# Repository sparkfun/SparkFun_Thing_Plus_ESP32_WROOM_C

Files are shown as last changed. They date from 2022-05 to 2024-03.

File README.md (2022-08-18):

SparkFun Thing Plus - ESP32 WROOM (USB-C)
========================================

SparkFun Thing Plus - ESP32 WROOM (USB-C) (https://www.sparkfun.com/products/20168)

*[SparkFun Thing Plus - ESP32 WROOM (USB-C) (WRL-20168)](https://www.sparkfun.com/products/20168)*

The [SparkFun Thing Plus - ESP32 WROOM (USB-C)](https://www.sparkfun.com/products/20168) is a comprehensive development platform for [Espressif's ESP32](https://espressif.com/en/products/hardware/esp32/overview). Thanks to the onboard ESP32 WROOM module, the SparkFun Thing Plus features 16MB of flash memory, 520kB of internal SRAM, an integrated 802.11 BGN WiFi transceiver and dual-mode Bluetooth capabilities, a JST connector to plug in a LiPo battery, a Qwiic connector, and 21 I/O pins. Add to that a rich set of peripherals ranging from capacitive touch sensors, Hall sensors, SD card interface, Ethernet, high-speed SPIs, UARTs, I2S, and I<sup>2</sup>C.

We took all the good from the original [ESP32 Thing Plus](https://www.sparkfun.com/products/15663) and sprinkled on some more. We upgraded to a USB-C connector that provides up to 2A of power, added a fuel gauge IC that will make sure you know your battery levels, included a NeoPixel (WS2812C) RGB LED is the perfect multi-status indicator, and threw a microSD connector on the back! Oh, and the new taller reset and boot buttons are **so** much easier to push! We even dedicated a voltage regulator to the Qwiic connector, which enables software power control to the Qwiic bus - great for low power logging!

Repository Contents
-------------------

* **[/Hardware](/Hardware/)** - Eagle design files (.brd, .sch)
* **[/Firmware](/Firmware/)** - Example sketches demonstrating extra peripherals

Documentation
--------------
* **[Hookup Guide](https://learn.sparkfun.com/tutorials/2353)** - Hookup guide for the ESP32 Thing Plus (USB-C).
* **[SparkFun Graphical Datasheets](https://github.com/sparkfun/Graphical_Datasheets)** -Graphical Datasheets for various SparkFun products.

Product Versions
----------------
* ESP32 Thing Plus (USB-C variant)
  * [WRL-20168](https://www.sparkfun.com/products/20168) - v1.0, Initial Release
  * [SPX-18018](https://www.sparkfun.com/products/18018) - SparkX Release
* ESP32 Thing Plus
  * [WRL-17381](https://www.sparkfun.com/products/17381) (u.FL variant) - v1.0, Initial Release
  * [WRL-15663](https://www.sparkfun.com/products/15663)- v2.0, Slight hardware update that includes a 10&ohm; series resistor between VUSB and CP2102
  * [WRL-14689](https://www.sparkfun.com/products/14689)- v1.0, Initial Release

License Information
-------------------

This product is _**open source**_! 

Please review the LICENSE.md file for license information. 

If you have any questions or concerns on licensing, please contact technical support on our [SparkFun forums](https://forum.sparkfun.com/viewforum.php?f=152).

Distributed as-is; no warranty is given.

- Your friends at SparkFun.

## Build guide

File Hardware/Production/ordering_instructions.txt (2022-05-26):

panel size, 107x204mm
PCB thickness, 1.6mm
number of layers, 2
soldermask color, Red
silkscreen color, White
oz copper, 1oz
finish, HASL lead free
stencils, none
pcs per panel, 12
min trace width, 0.1270mm / 0.0050in
min drill size, 0.3048mm / 0.0120in

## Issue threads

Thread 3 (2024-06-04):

High Leakage From VBAT to VBUS

DominicChm, 2024-06-04:
This issue is spawned from the Sparkfun forum post [here](https://forum.sparkfun.com/viewtopic.php?p=249708#p249708).

I've noticed the [Thing Plus USB-C](https://www.sparkfun.com/products/20168) has an issue with high leakage from VBATT to VBUS when only the battery is connected. From testing I've done on my own board, the issue appears to be that D4  has extremely poor reverse leakage (along the lines of the [Infineon BAT60A](https://www.infineon.com/dgdl/Infineon-BAT60ASERIES-DS-v01_01-en.pdf?fileId=db3a304313d846880113def70c9304a9)) which allows a non-negligible amount of current to flow through R7 when on battery.

<details>
  <summary>Schematic</summary>

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

</details>

On my board, this results in VBUS being pulled to 2.5V when on battery power when it really should be ~0V. Given the 10K pulldown on this rail, it seems about 250uA is reverse leaking through the diode. The ESP32's deep sleep current is specced at ~10uA, so this leakage represents an obstacle to battery-powered projects.

This issue also prevents effectively recognizing when power is coming from USB vs when it's coming from battery b/c the rail never drops low enough to be registered as a digital LOW by the ESP32 (.25v). In my application this prevents me from setting the ESP to wake from deep sleep when USB power is supplied. I've mitigated by adding a 500ohm resistor to pull the rail low harder but I really wish this wasn't a problem in the first place.

Whatever diode is in the BOM really ought to be replaced with one that has a better reverse leakage spec. It looks like there's probably enough space on the PCB to even include one with a larger package which should allow the existing spec to be met without the reverse leakage problem.

DominicChm, 2024-06-06:
Update: Bodged in a random large(r) diode from a scrap PCB I had lying around and the issue is resolved as suspected. I now measure `.0002v`  under the same conditions as above. Original diode is to the right of the bodged diode for reference.

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

brhoff720, 2024-06-07:
Thanks Dominic!  Glad you were able to get the performance you needed.

We appreciate the feedback on this.  We'll need to evaluate and likely get
a bom change made,.  It might be a bit before it makes it into production.

Thanks again!

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

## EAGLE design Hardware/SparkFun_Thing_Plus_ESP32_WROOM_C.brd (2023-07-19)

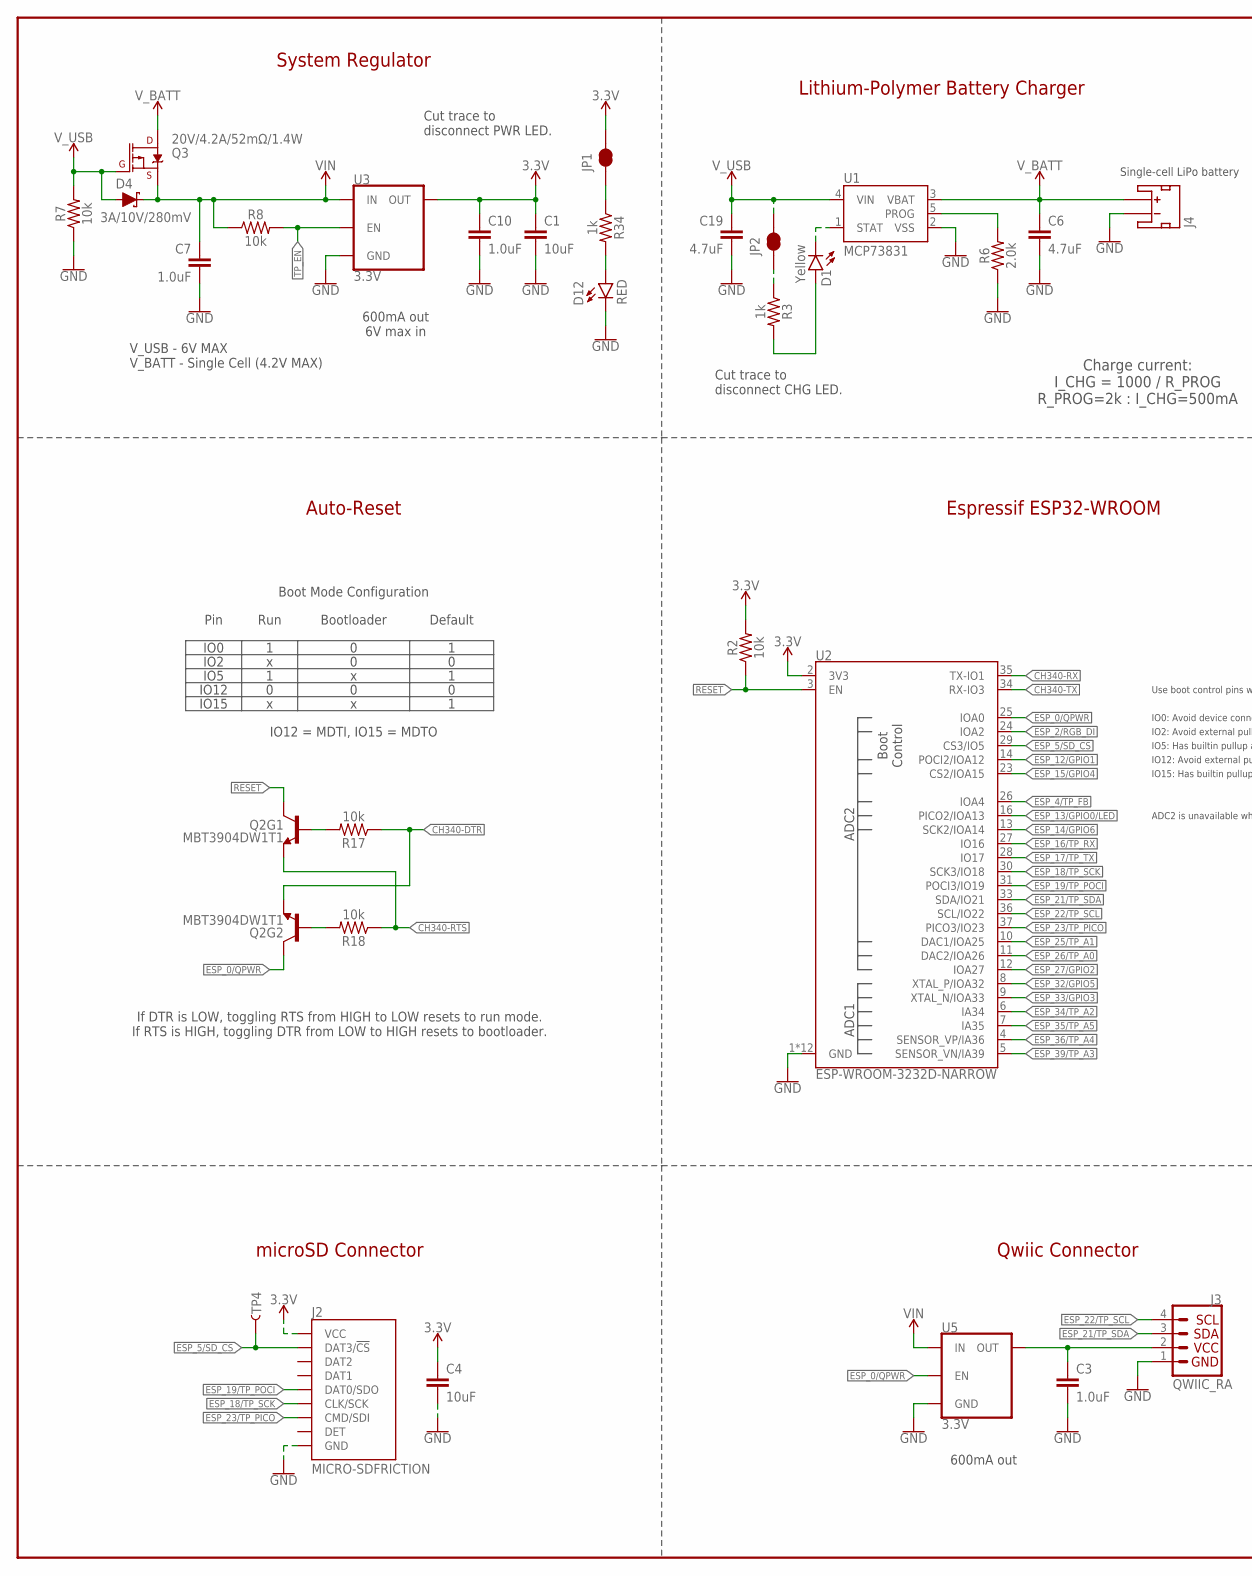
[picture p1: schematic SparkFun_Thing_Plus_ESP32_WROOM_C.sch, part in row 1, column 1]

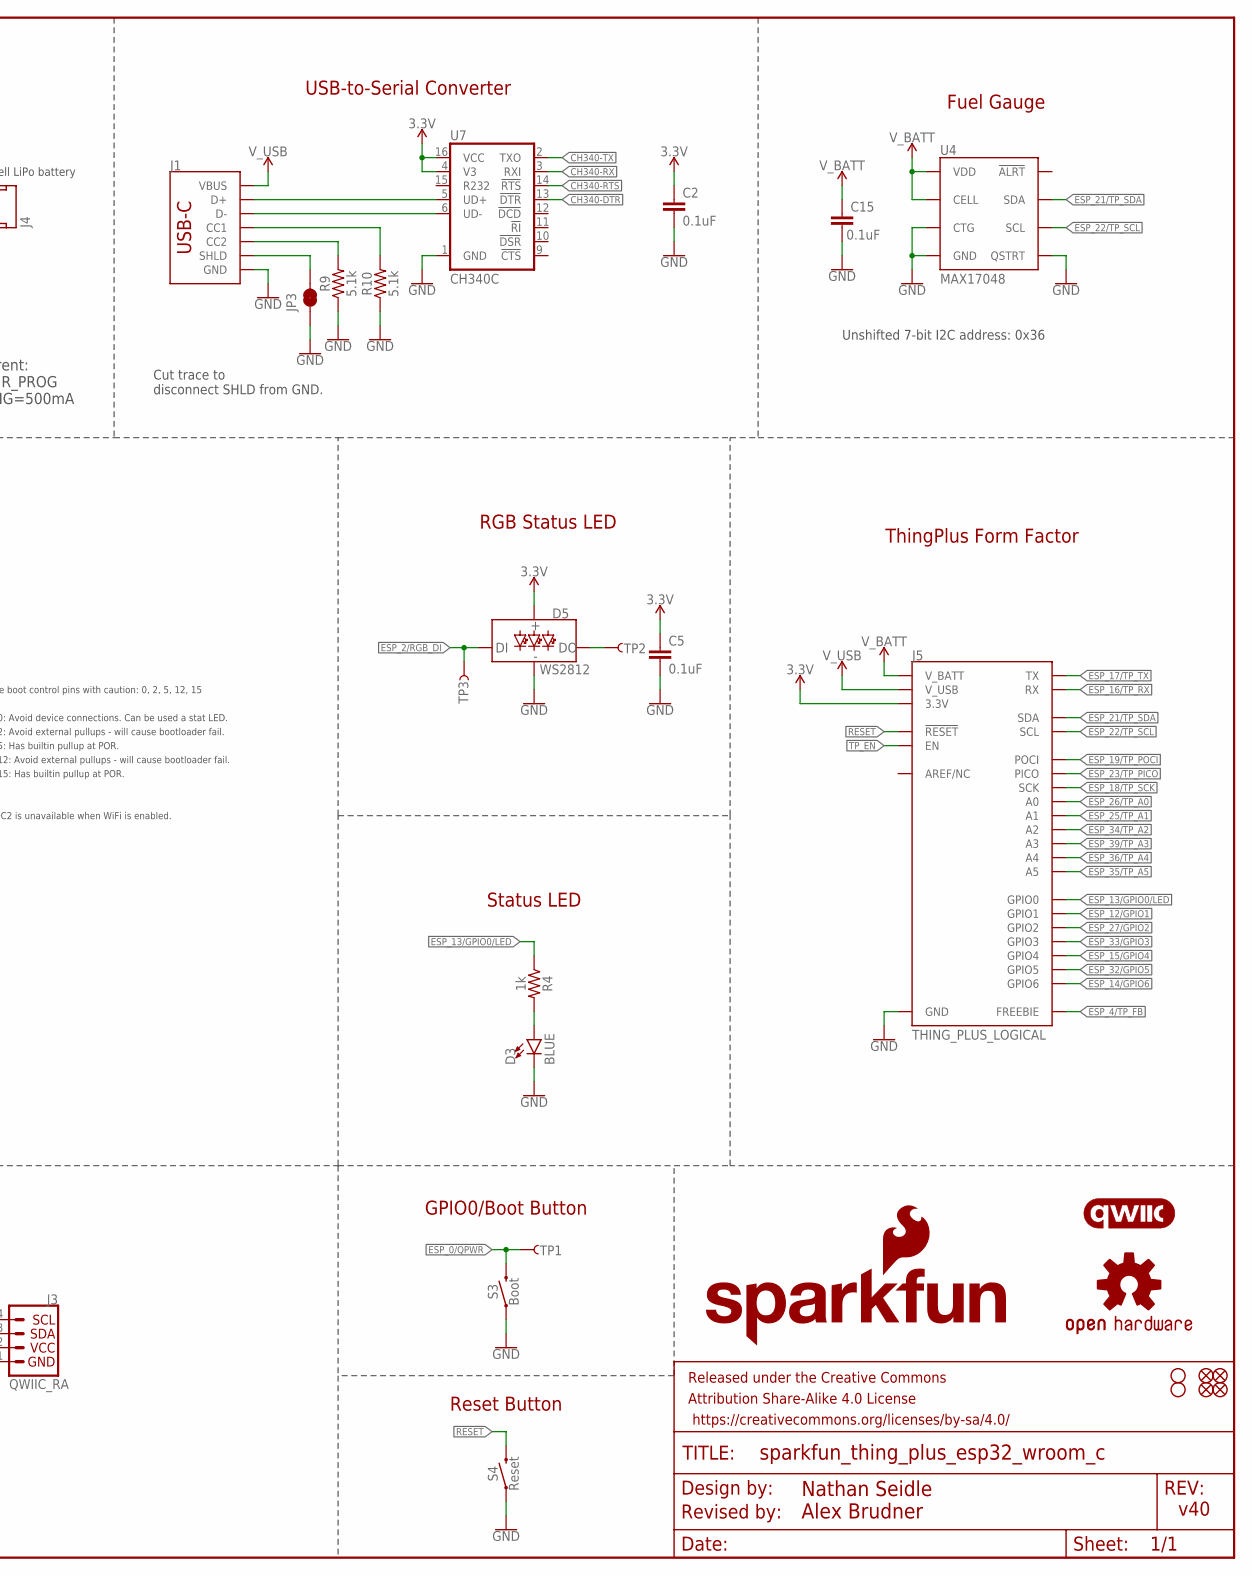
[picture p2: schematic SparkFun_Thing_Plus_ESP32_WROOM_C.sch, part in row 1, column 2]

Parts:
C1, C4: 10uF; 0402-TIGHT
C2, C5, C15: 0.1uF; 0402-TIGHT
C3, C7, C10: 1.0uF; 0402-TIGHT
C6: 4.7uF; 0402-TIGHT
C19: 4.7uF; 0603
D1: Yellow; LED-0603
D3: BLUE; LED-0603
D4: 3A/10V/280mV; SOD-323
D5: WS2812; WS2812-2020
D12: RED; LED-0603
FD1, FD2, FD3, FD4: FIDUCIALUFIDUCIAL; FIDUCIAL-MICRO
FRAME1: FRAME-LEDGER; CREATIVE_COMMONS
H1, H2: STAND-OFFTIGHT; STAND-OFF-TIGHT
J1: USB_C_2-LAYER_PADS; USB-C-16P-2LAYER-PADS
J2: MICRO-SDFRICTION; MICROSD_TINY
J3: QWIIC_RA; JST04_1MM_RA
J4: JST_2MM_MALE; JST-2-SMD
J5: THING_PLUS_LOGICAL; THING_PLUS
JP1, JP2, JP3: JUMPER-SMT_2_NC_TRACE_SILK; SMT-JUMPER_2_NC_TRACE_SILK
LOGO1: SFE_LOGO_NAME_FLAME.1_INCH; SFE_LOGO_NAME_FLAME_.1
LOGO2: OSHW-LOGOMINI; OSHW-LOGO-MINI
LOGO4: QWIIC_LOGO_4MM; QWIIC_4MM
Q2: MBT3904DW1T1; SC70-6
Q3: 20V/4.2A/52mΩ/1.4W; SOT23-3
R2, R7, R8, R17, R18: 10k; 0402-TIGHT
R3, R4, R34: 1k; 0402-TIGHT
R6: 2.0k; 0603
R9, R10: 5.1k; 0402-TIGHT
S3: Boot; TACTILE_SWITCH_SMD_4.6X2.8MM
S4: Reset; TACTILE_SWITCH_SMD_4.6X2.8MM
TP1, TP2, TP3, TP4: TEST-POINT3X5; PAD.03X.05
U1: MCP73831; SOT23-5
U2: ESP-WROOM-3232D-NARROW; ESP-WROOM-32D-NARROW
U3, U5: 3.3V; SOT23-5
U4: MAX17048; DFN-8
U7: CH340C; SO016

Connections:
3.3V: C1.1, C2.1, C4.1, C5.1, C10.1, D5.VCC, J2.4 (VCC), J5.27 (3.3V), JP1.2, R2.2, U2.2 (3V3), U3.5 (OUT), U7.4 (V3), U7.16 (VCC)
!RESET!: J5.28 (!RESET), Q2.3 (C), R2.1, S4.3 (2), S4.4 (2), U2.3 (EN)
CH340-DTR: Q2.1 (E), R17.1, U7.13 (!DTR)
CH340-RTS: Q2.4 (E), R18.1, U7.14 (!RTS)
CH340-RX: U2.35 (TX-IO1), U7.3 (RXI)
CH340-TX: U2.34 (RX-IO3), U7.2 (TXO)
CHG_LED: D1.A, R3.2
D+: J1.A6 (D+), J1.B6 (D+), U7.5 (UD+)
D-: J1.A7 (D-), J1.B7 (D-), U7.6 (UD-)
DTR-10K: Q2.5 (B), R17.2
ESP_0/QPWR: Q2.6 (C), S3.3 (2), S3.4 (2), TP1.1, U2.25 (IOA0), U5.3 (EN)
ESP_2/RGB_DI: D5.DI, TP3.1, U2.24 (IOA2)
ESP_4/TP_FB: J5.13 (FREEBIE), U2.26 (IOA4)
ESP_5/SD_CS: J2.2 (DAT3/!CS!), TP4.1, U2.29 (CS3/IO5)
ESP_12/GPIO1: J5.8 (GPIO1), U2.14 (POCI2/IOA12)
ESP_13/GPIO0/LED: J5.9 (GPIO0), R4.1, U2.16 (PICO2/IOA13)
ESP_14/GPIO6: J5.3 (GPIO6), U2.13 (SCK2/IOA14)
ESP_15/GPIO4: J5.5 (GPIO4), U2.23 (CS2/IOA15)
ESP_16/TP_RX: J5.15 (RX), U2.27 (IO16)
ESP_17/TP_TX: J5.14 (TX), U2.28 (IO17)
ESP_18/TP_SCK: J2.5 (CLK/SCK), J5.18 (SCK), U2.30 (SCK3/IO18)
ESP_19/TP_POCI: J2.7 (DAT0/SDO), J5.16 (POCI), U2.31 (POCI3/IO19)
ESP_21/TP_SDA: J3.3, J5.1 (SDA), U2.33 (SDA/IO21), U4.8 (SDA)
ESP_22/TP_SCL: J3.4, J5.2 (SCL), U2.36 (SCL/IO22), U4.7 (SCL)
ESP_23/TP_PICO: J2.3 (CMD/SDI), J5.17 (PICO), U2.37 (PICO3/IO23)
ESP_25/TP_A1: J5.23 (A1), U2.10 (DAC1/IOA25)
ESP_26/TP_A0: J5.24 (A0), U2.11 (DAC2/IOA26)
ESP_27/GPIO2: J5.7 (GPIO2), U2.12 (IOA27)
ESP_32/GPIO5: J5.4 (GPIO5), U2.8 (XTAL_P/IOA32)
ESP_33/GPIO3: J5.6 (GPIO3), U2.9 (XTAL_N/IOA33)
ESP_34/TP_A2: J5.22 (A2), U2.6 (IA34)
ESP_35/TP_A5: J5.19 (A5), U2.7 (IA35)
ESP_36/TP_A4: J5.20 (A4), U2.4 (SENSOR_VP/IA36)
ESP_39/TP_A3: J5.21 (A3), U2.5 (SENSOR_VN/IA39)
GND: C1.2, C2.2, C3.2, C4.2, C5.2, C6.2, C7.2, C10.2, C15.2, C19.2, D3.C, D5.GND, D12.C, J1.GND, J1.GND2 (GND), J2.6 (GND), J2.GND1 (GND), J2.GND2 (GND), J2.GND3 (GND), J2.GND4 (GND), J2.GND5 (GND), J2.GND6 (GND), J3.1, J4.1 (-), J5.25 (GND), JP3.1, R6.1, R7.1, R9.1, R10.1, S3.1, S3.2 (1), S4.1, S4.2 (1), U1.2 (VSS), U2.1 (GND), U2.15 (GND), U2.38 (GND), U2.GND1 (GND), U2.GNDT1 (GND), U2.GNDT2 (GND), U2.GNDT3 (GND), U2.GNDT4 (GND), U2.GNDT5 (GND), U2.GNDT6 (GND), U2.GNDT7 (GND), U2.GNDT8 (GND), U3.2 (GND), U4.1 (CTG), U4.4 (GND), U4.6 (QSTRT), U4.9 (GND), U5.2 (GND), U7.1 (GND)
unnamed: JP1.1, R34.1
unnamed: D3.A, R4.2
unnamed: D5.DO, TP2.1
unnamed: JP2.1, R3.1
unnamed: J1.B5 (CC2), R9.2
unnamed: J1.A5 (CC1), R10.2
unnamed: D1.C, U1.1 (STAT)
unnamed: J1.SHLD1 (SHLD), J1.SHLD2 (SHLD), J1.SHLD3 (SHLD), J1.SHLD4 (SHLD), JP3.2
unnamed: R6.2, U1.5 (PROG)
unnamed: D12.A, R34.2
QWIIC_PWR: C3.1, J3.2, U5.5 (OUT)
RTS-10K: Q2.2 (B), R18.2
TP_EN: J5.11 (EN), R8.2, U3.3 (EN)
VIN: C7.1, D4.C, Q3.2 (S), R8.1, U3.1 (IN), U5.1 (IN)
V_BATT: C6.1, C15.1, J4.2 (+), J5.12 (V_BATT), Q3.3 (D), U1.3 (VBAT), U4.2 (CELL), U4.3 (VDD)
V_USB: C19.1, D4.A, J1.VBUS1 (VBUS), J1.VBUS2 (VBUS), J5.10 (V_USB), JP2.2, Q3.1 (G), R7.2, U1.4 (VIN)

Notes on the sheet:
USB-to-Serial Converter
Single-cell LiPo battery
Charge current: I_CHG = 1000 / R_PROG R_PROG=2k : I_CHG=500mA
System Regulator
Lithium-Polymer Battery Charger
600mA out 6V max in
Auto-Reset
Espressif ESP32-WROOM
Reset Button
ThingPlus Form Factor
v40
If DTR is LOW, toggling RTS from HIGH to LOW resets to run mode. If RTS is HIGH, toggling DTR from LOW to HIGH resets to bootloader.
Qwiic Connector
Status LED
GPIO0/Boot Button
V_USB - 6V MAX V_BATT - Single Cell (4.2V MAX)
Pin
IO0
IO2
IO12
IO15
IO5
Run
Bootloader
Default
IO12 = MDTI, IO15 = MDTO
Boot Mode Configuration
IO0: Avoid device connections. Can be used a stat LED.
ADC2 is unavailable when WiFi is enabled.
IO12: Avoid external pullups - will cause bootloader fail.
Use boot control pins with caution: 0, 2, 5, 12, 15
IO2: Avoid external pullups - will cause bootloader fail.
Fuel Gauge
600mA out
RGB Status LED
microSD Connector
IO15: Has builtin pullup at POR.
IO5: Has builtin pullup at POR.
Cut trace to disconnect CHG LED.
Cut trace to disconnect PWR LED.

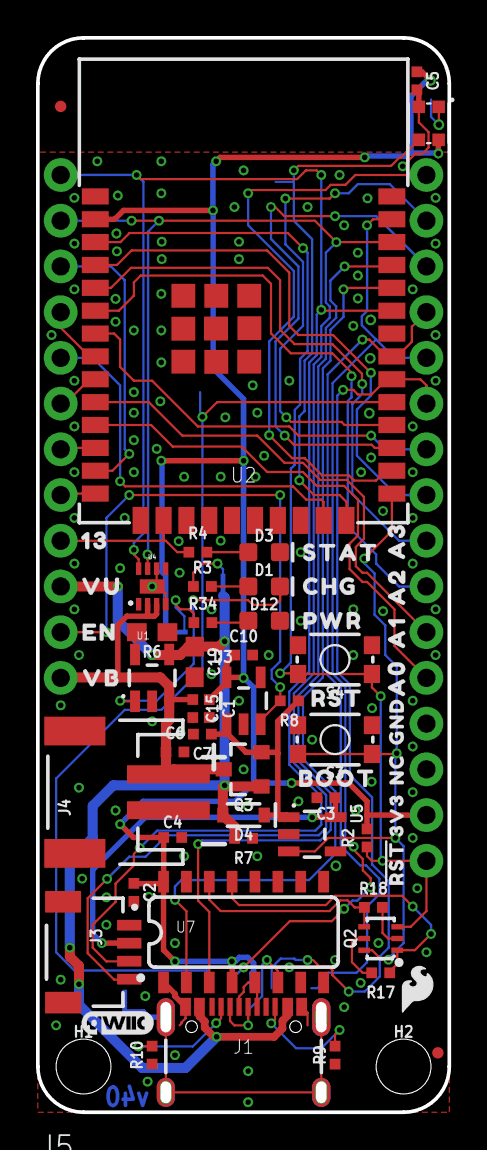
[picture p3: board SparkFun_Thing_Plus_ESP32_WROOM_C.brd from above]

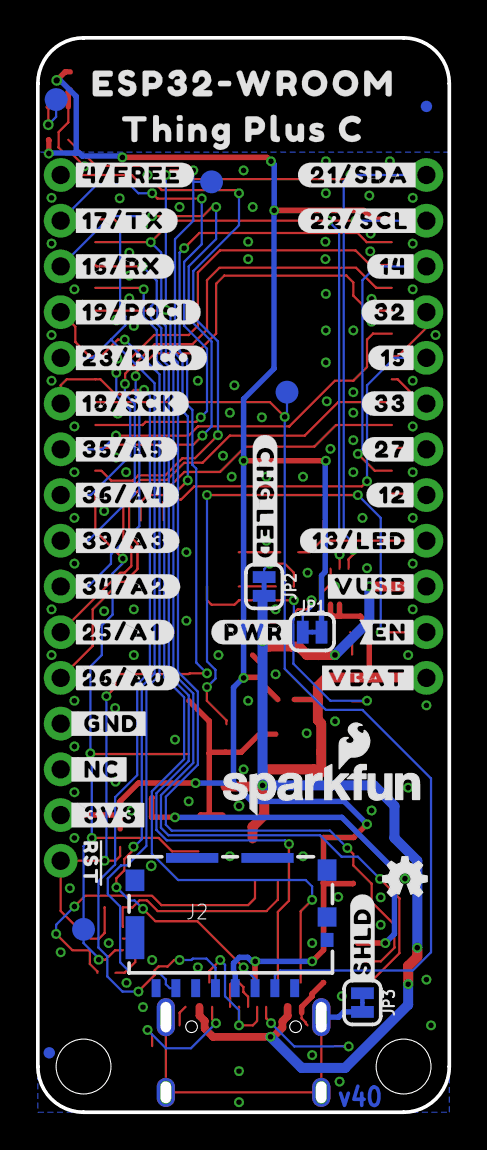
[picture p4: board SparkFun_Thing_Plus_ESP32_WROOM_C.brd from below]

Board: 2 copper layers, 22.9 x 59.7 mm, 110 parts (46 on the bottom side), 51 nets.

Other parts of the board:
U$1: SFE_LOGO_FLAME_STOP_.1
U$2: #23#PICO#0
U$3: #19#POCI#0
U$4: #4#FREE#0
U$5: #CHG_LED#0
U$6: ESP32#WROOM0
U$7: THING_PLUS_C0
U$8: #SHLD#0
U$9: #_GND#0
U$10: #_NC#0
U$11: #_3V3#0
U$12: SFE_LOGO_FLAME_.1
U$23: 3V30
U$24: CHG1
U$25: PWR2
U$26: STAT0
U$68: A03
U$69: A12
U$70: A21
U$71: A30
U$72: #17#TX#0
U$73: VB1
U$74: EN3
U$75: GND1
U$76: VU0
U$77: 130
U$78: BOOT0
U$79, U$109: #RST#0
U$80: RST0
U$81: #16#RX#0
U$83: #18#SCK#0
U$84: #35#A5#0
U$85: #36#A4#0
U$86: #25#A1#2
U$87: #26#A0#3
U$88: #34#A2#1
U$89: #39#A3#0
U$90: #12#4
U$91: #14#9
U$92: #15#7
U$93: #27#5
U$94: #32#8
U$95: #33#6
U$96: #EN#1
U$97: #VBAT#0
U$98: #VUSB#2
U$99: #13#LED#0
U$100: #21#SDA#1
U$101: #22#SCL#0
U$102: #PWR#0
U$107: NC0

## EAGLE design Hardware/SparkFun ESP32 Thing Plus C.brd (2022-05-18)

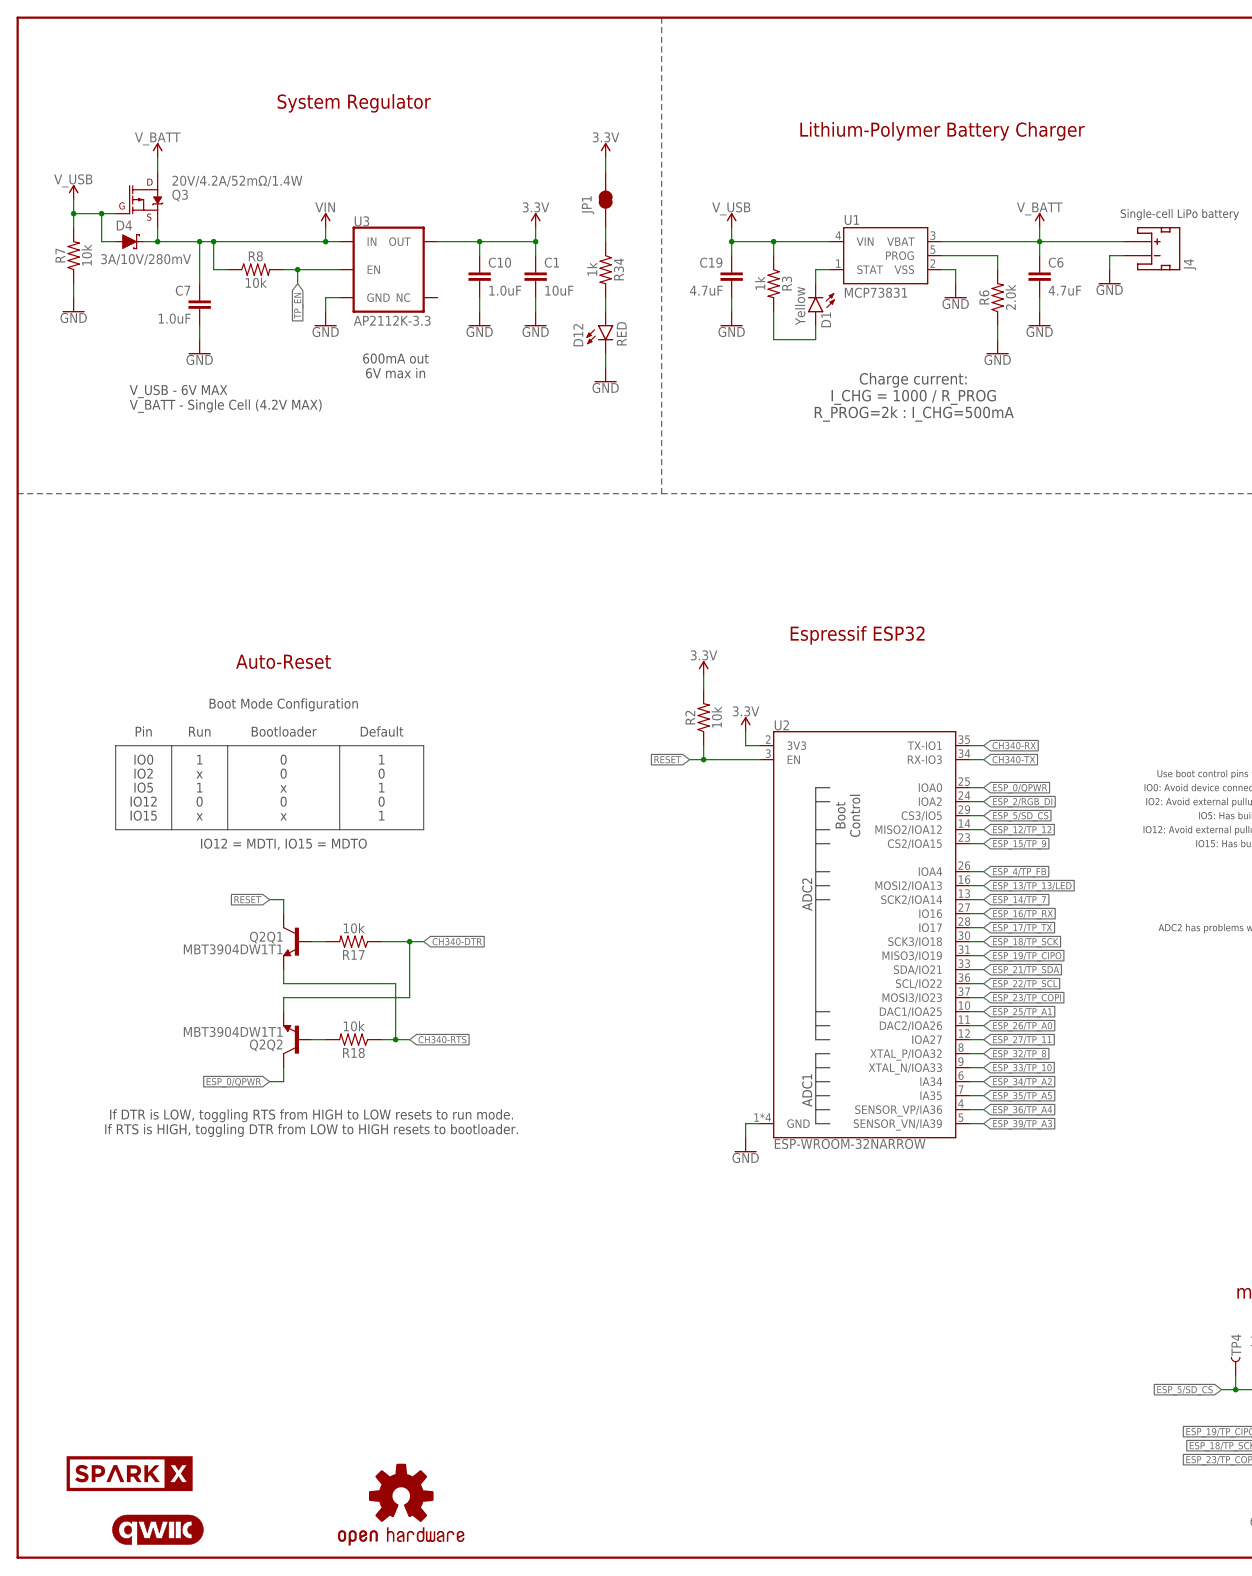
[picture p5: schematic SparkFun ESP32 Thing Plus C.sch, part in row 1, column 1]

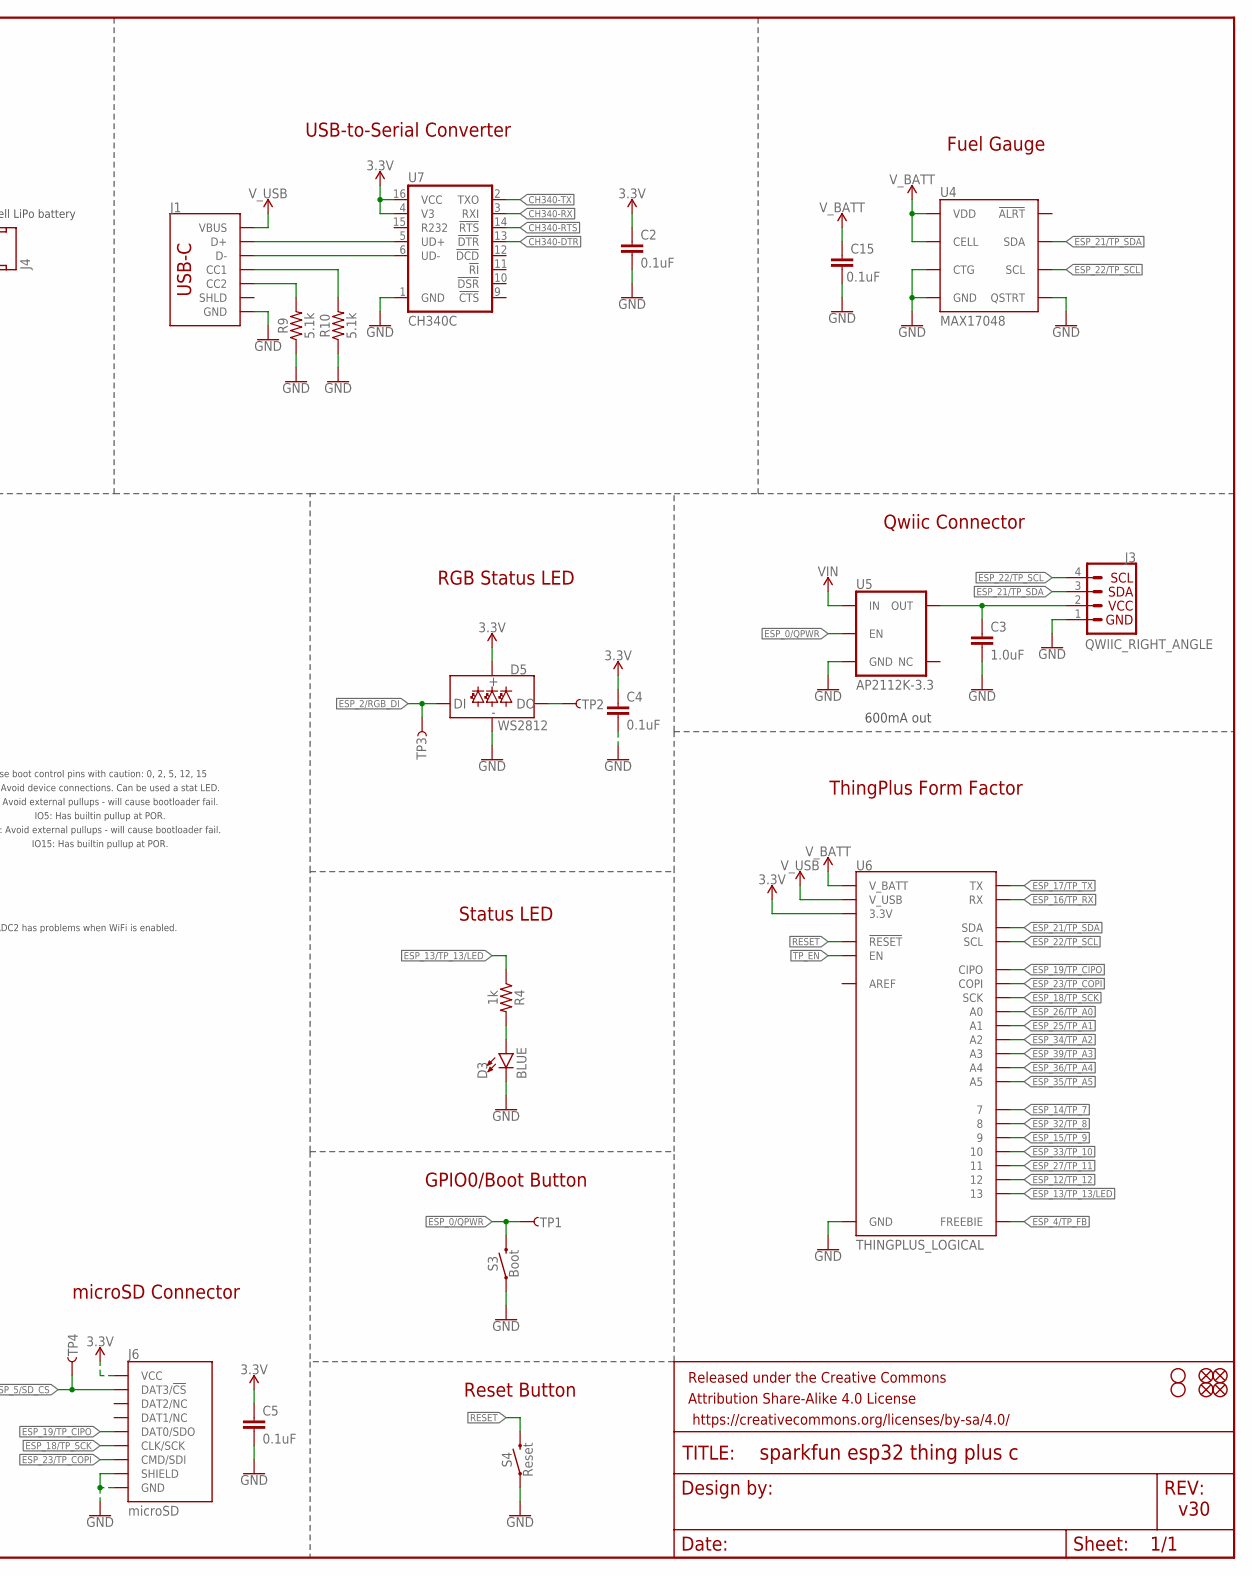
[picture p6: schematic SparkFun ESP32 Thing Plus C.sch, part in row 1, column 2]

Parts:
C1: 10uF; 0402-TIGHT
C2, C4, C5, C15: 0.1uF; 0402-TIGHT
C3, C7, C10: 1.0uF; 0402-TIGHT
C6: 4.7uF; 0402-TIGHT
C19: 4.7uF; 0603
D1: Yellow; LED-0603
D3: BLUE; LED-0603
D4: 3A/10V/280mV; SOD-323
D5: WS2812; WS2812-2020
D12: RED; LED-0603
FD1, FD2, FD3, FD4: FIDUCIALUFIDUCIAL; FIDUCIAL-MICRO
FRAME1: FRAME-LEDGER; CREATIVE_COMMONS
H1, H2: STAND-OFFTIGHT; STAND-OFF-TIGHT
J1: USB_C_2-LAYER_PADS; USB-C-16P-2LAYER-PADS
J3: QWIIC_RIGHT_ANGLE; JST04_1MM_RA
J4: JST_2MM_MALE; JST-2-SMD
J6: microSD; MICRO-SD-SOCKET
JP1: JUMPER-SMT_2_NC_TRACE_SILK; SMT-JUMPER_2_NC_TRACE_SILK
LOGO2: OSHW-LOGOMINI; OSHW-LOGO-MINI
LOGO4: QWIIC_LOGO_4MM; QWIIC_4MM
Q2: MBT3904DW1T1; SC70-6
Q3: 20V/4.2A/52mΩ/1.4W; SOT23-3
R2, R7, R8, R17, R18: 10k; 0402-TIGHT
R3, R4, R34: 1k; 0402-TIGHT
R6: 2.0k; 0603
R9, R10: 5.1k; 0402-TIGHT
S3: Boot; TACTILE_SWITCH_SMD_4.6X2.8MM
S4: Reset; TACTILE_SWITCH_SMD_4.6X2.8MM
TP1, TP2, TP3, TP4: TEST-POINT3X5; PAD.03X.05
U1: MCP73831; SOT23-5
U2: ESP-WROOM-32NARROW; ESP-WROOM-32-NARROW
U3, U5: AP2112K-3.3; SOT23-5
U4: MAX17048; DFN-8
U6: THINGPLUS_LOGICAL; THINGPLUS_FOOTPRINT
U7: CH340C; SO016
U$1: SPARKX-LOGO4; SPARKX-MEDIUM

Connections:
3.3V: C1.1, C2.1, C4.1, C5.1, C10.1, D5.VCC, J6.VCC, JP1.2, R2.2, U2.2 (3V3), U3.5 (OUT), U6.3V3 (3.3V), U7.4 (V3), U7.16 (VCC)
!RESET!: Q2.3 (C), R2.1, S4.3 (2), S4.4 (2), U2.3 (EN), U6.RST (!RESET)
CH340-DTR: Q2.1 (E), R17.1, U7.13 (!DTR)
CH340-RTS: Q2.4 (E), R18.1, U7.14 (!RTS)
CH340-RX: U2.35 (TX-IO1), U7.3 (RXI)
CH340-TX: U2.34 (RX-IO3), U7.2 (TXO)
CHG: D1.C, U1.1 (STAT)
CHG_LED: D1.A, R3.2
D+: J1.A6 (D+), J1.B6 (D+), U7.5 (UD+)
D-: J1.A7 (D-), J1.B7 (D-), U7.6 (UD-)
DTR-10K: Q2.5 (B), R17.2
ESP_0/QPWR: Q2.6 (C), S3.3 (2), S3.4 (2), TP1.P$1, U2.25 (IOA0), U5.3 (EN)
ESP_2/RGB_DI: D5.DI, TP3.P$1, U2.24 (IOA2)
ESP_4/TP_FB: U2.26 (IOA4), U6.FREEBIE
ESP_5/SD_CS: J6.CS/DAT3 (DAT3/!CS!), TP4.P$1, U2.29 (CS3/IO5)
ESP_12/TP_12: U2.14 (MISO2/IOA12), U6.12
ESP_13/TP_13/LED: R4.1, U2.16 (MOSI2/IOA13), U6.13
ESP_14/TP_7: U2.13 (SCK2/IOA14), U6.7
ESP_15/TP_9: U2.23 (CS2/IOA15), U6.9
ESP_16/TP_RX: U2.27 (IO16), U6.RX
ESP_17/TP_TX: U2.28 (IO17), U6.TX
ESP_18/TP_SCK: J6.SCLK (CLK/SCK), U2.30 (SCK3/IO18), U6.SCK
ESP_19/TP_CIPO: J6.DO/DAT0 (DAT0/SDO), U2.31 (MISO3/IO19), U6.CIPO
ESP_21/TP_SDA: J3.3, U2.33 (SDA/IO21), U4.8 (SDA), U6.SDA
ESP_22/TP_SCL: J3.4, U2.36 (SCL/IO22), U4.7 (SCL), U6.SCL
ESP_23/TP_COPI: J6.DI/CMD (CMD/SDI), U2.37 (MOSI3/IO23), U6.COPI
ESP_25/TP_A1: U2.10 (DAC1/IOA25), U6.A1
ESP_26/TP_A0: U2.11 (DAC2/IOA26), U6.A0
ESP_27/TP_11: U2.12 (IOA27), U6.11
ESP_32/TP_8: U2.8 (XTAL_P/IOA32), U6.8
ESP_33/TP_10: U2.9 (XTAL_N/IOA33), U6.10
ESP_34/TP_A2: U2.6 (IA34), U6.A2
ESP_35/TP_A5: U2.7 (IA35), U6.A5
ESP_36/TP_A4: U2.4 (SENSOR_VP/IA36), U6.A4
ESP_39/TP_A3: U2.5 (SENSOR_VN/IA39), U6.A3
GND: C1.2, C2.2, C3.2, C4.2, C5.2, C6.2, C7.2, C10.2, C15.2, C19.2, D3.C, D5.GND, D12.C, J1.GND, J1.GND2 (GND), J3.1, J4.1 (-), J6.CD1 (SHIELD), J6.GND, J6.GND1 (GND), J6.GND3 (GND), R6.1, R7.1, R9.1, R10.1, S3.1, S3.2 (1), S4.1, S4.2 (1), U1.2 (VSS), U2.1 (GND), U2.15 (GND), U2.38 (GND), U2.GND, U3.2 (GND), U4.1 (CTG), U4.4 (GND), U4.6 (QSTRT), U4.9 (GND), U5.2 (GND), U6.GND, U7.1 (GND)
unnamed: JP1.1, R34.1
unnamed: D3.A, R4.2
unnamed: D5.DO, TP2.P$1
unnamed: J1.B5 (CC2), R9.2
unnamed: J1.A5 (CC1), R10.2
unnamed: R6.2, U1.5 (PROG)
unnamed: D12.A, R34.2
QWIIC_PWR: C3.1, J3.2, U5.5 (OUT)
RTS-10K: Q2.2 (B), R18.2
TP_EN: R8.2, U3.3 (EN), U6.EN
VIN: C7.1, D4.C, Q3.2 (S), R8.1, U3.1 (IN), U5.1 (IN)
V_BATT: C6.1, C15.1, J4.2 (+), Q3.3 (D), U1.3 (VBAT), U4.2 (CELL), U4.3 (VDD), U6.V_BATT
V_USB: C19.1, D4.A, J1.VBUS1 (VBUS), J1.VBUS2 (VBUS), Q3.1 (G), R3.1, R7.2, U1.4 (VIN), U6.V_USB

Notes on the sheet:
USB-to-Serial Converter
Single-cell LiPo battery
Charge current: I_CHG = 1000 / R_PROG R_PROG=2k : I_CHG=500mA
System Regulator
Lithium-Polymer Battery Charger
600mA out 6V max in
Auto-Reset
Espressif ESP32
Reset Button
ThingPlus Form Factor
v30
If DTR is LOW, toggling RTS from HIGH to LOW resets to run mode. If RTS is HIGH, toggling DTR from LOW to HIGH resets to bootloader.
Qwiic Connector
Status LED
GPIO0/Boot Button
V_USB - 6V MAX V_BATT - Single Cell (4.2V MAX)
Pin
IO0
IO2
IO12
IO15
IO5
Run
Bootloader
Default
IO12 = MDTI, IO15 = MDTO
Boot Mode Configuration
IO0: Avoid device connections. Can be used a stat LED.
ADC2 has problems when WiFi is enabled.
IO12: Avoid external pullups - will cause bootloader fail.
Use boot control pins with caution: 0, 2, 5, 12, 15
IO2: Avoid external pullups - will cause bootloader fail.
Fuel Gauge
600mA out
RGB Status LED
microSD Connector
IO15: Has builtin pullup at POR.
IO5: Has builtin pullup at POR.

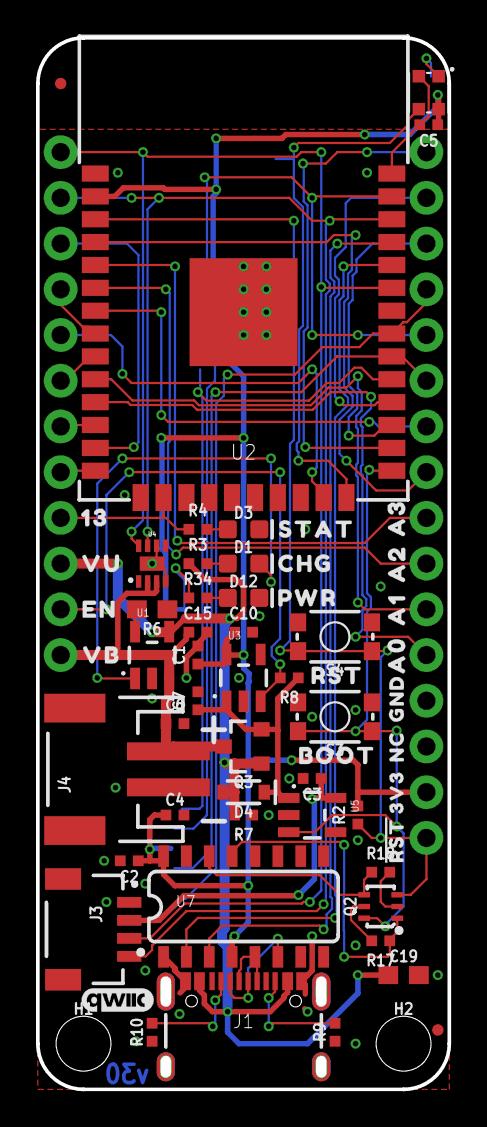
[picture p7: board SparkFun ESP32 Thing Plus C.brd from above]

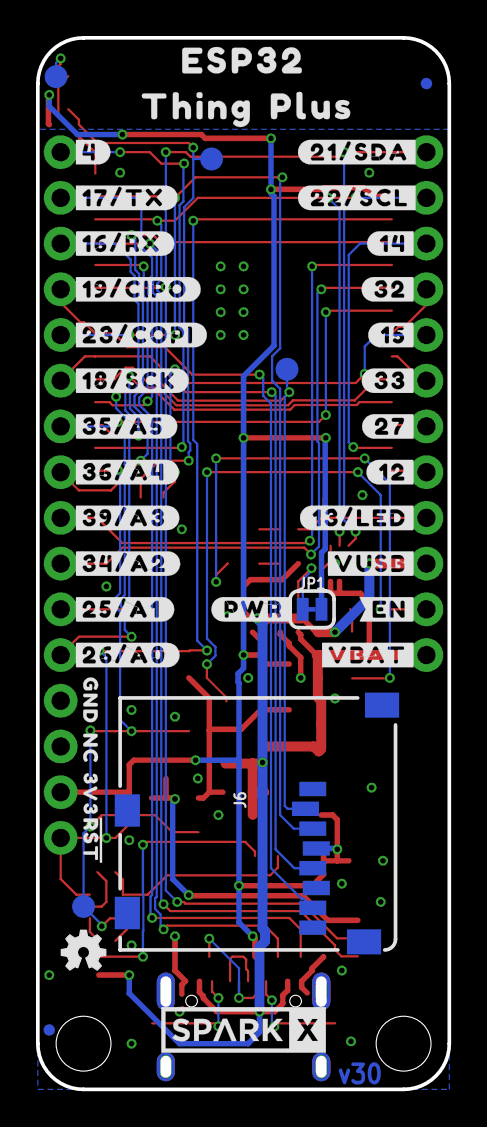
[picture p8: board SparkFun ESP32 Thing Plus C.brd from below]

Board: 2 copper layers, 22.9 x 58.4 mm, 106 parts (42 on the bottom side), 49 nets.

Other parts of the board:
U$23, U$108: 3V30
U$24: CHG1
U$25: PWR2
U$26: STAT0
U$56, U$75: GND1
U$57: #4#0
U$59: ORDERING_INSTRUCTIONS
U$62: #23#COPI#0
U$68: A03
U$69: A12
U$70: A21
U$71: A30
U$72: #17#TX#0
U$73: VB1
U$74: EN3
U$76: VU0
U$77: 130
U$78: BOOT0
U$79, U$109: #RST#0
U$80: RST0
U$81: #16#RX#0
U$82: #19#CIPO#0
U$83: #18#SCK#0
U$84: #35#A5#0
U$85: #36#A4#0
U$86: #25#A1#2
U$87: #26#A0#3
U$88: #34#A2#1
U$89: #39#A3#0
U$90: #12#4
U$91: #14#9
U$92: #15#7
U$93: #27#5
U$94: #32#8
U$95: #33#6
U$96: #EN#1
U$97: #VBAT#0
U$98: #VUSB#2
U$99: #13#LED#0
U$100: #21#SDA#1
U$101: #22#SCL#0
U$102: #PWR#0
U$103: ESP320
U$104: THING1
U$105: PLUS2
U$106, U$107: NC0

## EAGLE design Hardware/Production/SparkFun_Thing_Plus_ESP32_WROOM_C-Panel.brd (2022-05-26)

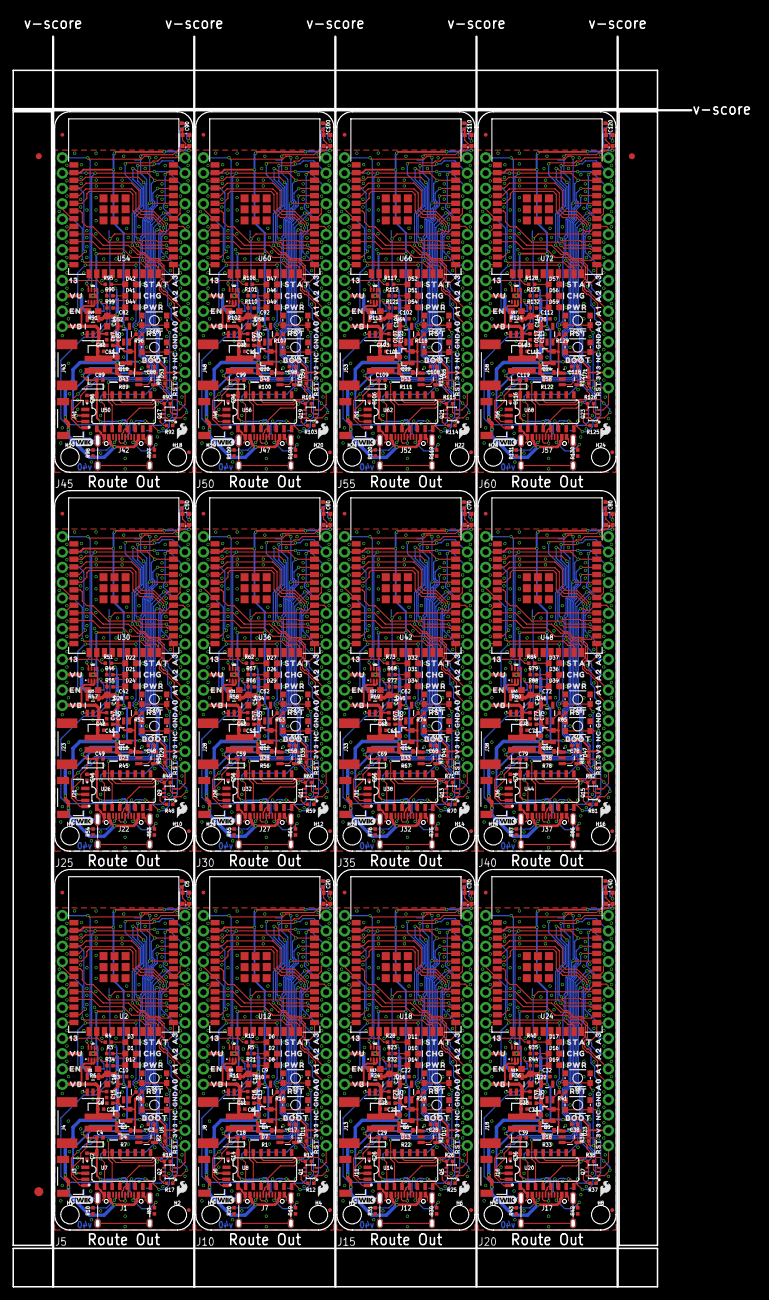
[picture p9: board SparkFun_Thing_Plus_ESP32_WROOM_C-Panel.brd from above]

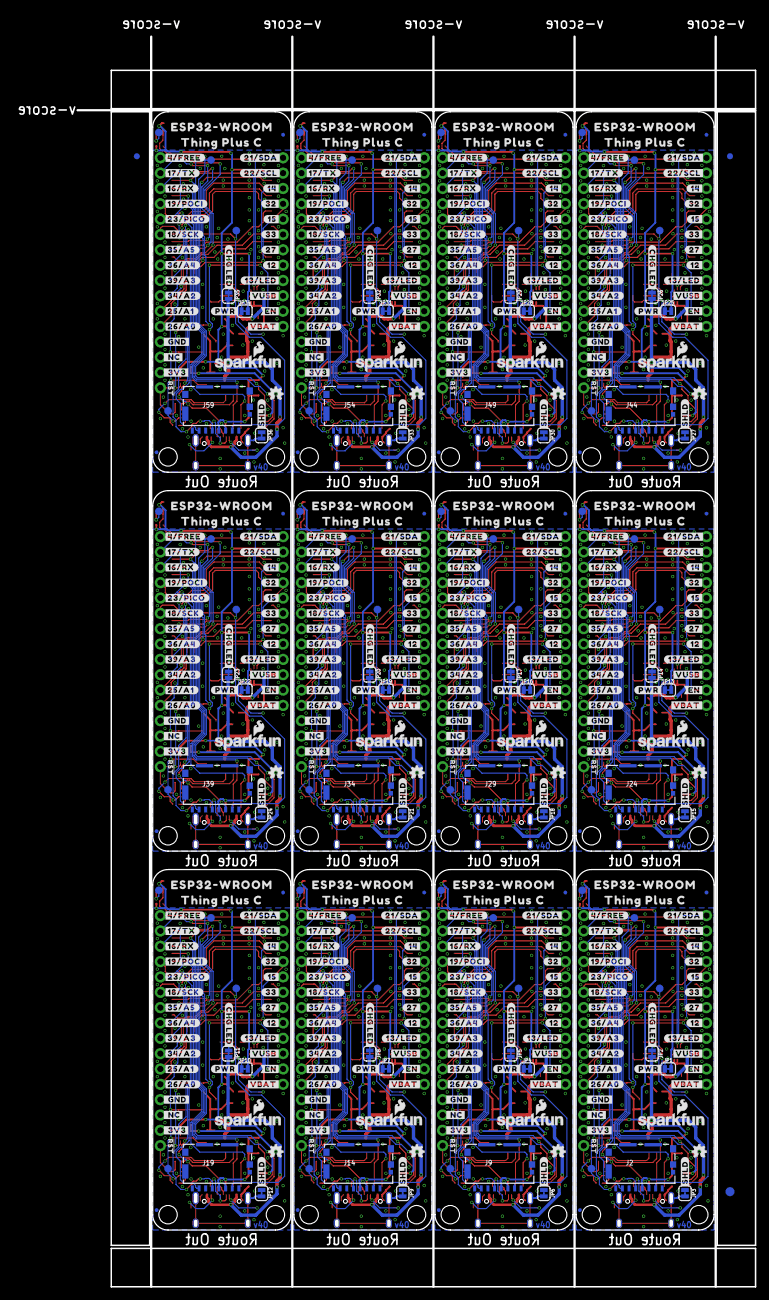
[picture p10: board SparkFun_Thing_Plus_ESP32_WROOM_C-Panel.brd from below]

Board: 2 copper layers, 112.3 x 207.0 mm, 1314 parts (555 on the bottom side), 612 nets.

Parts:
C1, C5, C13, C20, C25, C30, C35, C40, C45, C50, C55, C60, C65, C70, C75, C80, C85, C90, C95, C100, C105, C110, C115, C120: 10uF; 0402-TIGHT
C2, C4, C14, C15, C16, C18, C26, C27, C29, C36, C37, C39, C46, C47, C49, C56, C57, C59, C66, C67, C69, C76, C77, C79, C86, C87, C89, C96, C97, C99, C106, C107, C109, C116, C117, C119: 0.1uF; 0402-TIGHT
C3, C7, C8, C9, C10, C17, C21, C22, C28, C31, C32, C38, C41, C42, C48, C51, C52, C58, C61, C62, C68, C71, C72, C78, C81, C82, C88, C91, C92, C98, C101, C102, C108, C111, C112, C118: 1.0uF; 0402-TIGHT
C6, C11, C23, C33, C43, C53, C63, C73, C83, C93, C103, C113: 4.7uF; 0402-TIGHT
C12, C19, C24, C34, C44, C54, C64, C74, C84, C94, C104, C114: 4.7uF; 0603
D1, D2, D10, D16, D21, D26, D31, D36, D41, D46, D51, D56: Yellow; LED-0603
D3, D6, D11, D17, D22, D27, D32, D37, D42, D47, D52, D57: BLUE; LED-0603
D4, D7, D13, D18, D23, D28, D33, D38, D43, D48, D53, D58: 3A/10V/280mV; SOD-323
D5, D9, D15, D20, D25, D30, D35, D40, D45, D50, D55, D60: WS2812; WS2812-2020
D8, D12, D14, D19, D24, D29, D34, D39, D44, D49, D54, D59: RED; LED-0603
E$1, E$2, E$3, E$4: FIDUCIAL-1X2
E$5, E$6: FIDUCIAL-1.5X3
FD1, FD2, FD3, FD4, FD5, FD6, FD7, FD8, FD9, FD10, FD11, FD12, FD13, FD14, FD15, FD16, FD17, FD18, FD19, FD20, FD21, FD22, FD23, FD24, FD25, FD26, FD27, FD28, FD29, FD30, FD31, FD32, FD33, FD34, FD35, FD36, FD37, FD38, FD39, FD40, FD41, FD42, FD43, FD44, FD45, FD46, FD47, FD48: FIDUCIALUFIDUCIAL; FIDUCIAL-MICRO
H1, H2, H3, H4, H5, H6, H7, H8, H9, H10, H11, H12, H13, H14, H15, H16, H17, H18, H19, H20, H21, H22, H23, H24: STAND-OFFTIGHT; STAND-OFF-TIGHT
J1, J7, J12, J17, J22, J27, J32, J37, J42, J47, J52, J57: USB-C-16P-2LAYER-PADS
J2, J9, J14, J19, J24, J29, J34, J39, J44, J49, J54, J59: MICRO-SDFRICTION; MICROSD_TINY
J3, J6, J11, J16, J21, J26, J31, J36, J41, J46, J51, J56: QWIIC_RA; JST04_1MM_RA
J4, J8, J13, J18, J23, J28, J33, J38, J43, J48, J53, J58: JST-2-SMD
J5, J10, J15, J20, J25, J30, J35, J40, J45, J50, J55, J60: THING_PLUS_LOGICAL; THING_PLUS
JP1, JP2, JP3, JP4, JP5, JP6, JP7, JP8, JP9, JP10, JP11, JP12, JP13, JP14, JP15, JP16, JP17, JP18, JP19, JP20, JP21, JP22, JP23, JP24, JP25, JP26, JP27, JP28, JP29, JP30, JP31, JP32, JP33, JP34, JP35, JP36: JUMPER-SMT_2_NC_TRACE_SILK; SMT-JUMPER_2_NC_TRACE_SILK
LOGO1, LOGO6, LOGO9, LOGO12, LOGO15, LOGO18, LOGO21, LOGO24, LOGO27, LOGO30, LOGO33, LOGO36: SFE_LOGO_NAME_FLAME.1_INCH; SFE_LOGO_NAME_FLAME_.1
LOGO2, LOGO3, LOGO7, LOGO10, LOGO13, LOGO16, LOGO19, LOGO22, LOGO25, LOGO28, LOGO31, LOGO34: OSHW-LOGOMINI; OSHW-LOGO-MINI
LOGO4, LOGO5, LOGO8, LOGO11, LOGO14, LOGO17, LOGO20, LOGO23, LOGO26, LOGO29, LOGO32, LOGO35: QWIIC_LOGO_4MM; QWIIC_4MM
Q1, Q2, Q5, Q7, Q9, Q11, Q13, Q15, Q17, Q19, Q21, Q23: MBT3904DW1T1; SC70-6
Q3, Q4, Q6, Q8, Q10, Q12, Q14, Q16, Q18, Q20, Q22, Q24: 20V/4.2A/52mΩ/1.4W; SOT23-3
R1, R2, R7, R8, R12, R13, R14, R16, R17, R18, R22, R25, R26, R27, R29, R33, R37, R38, R39, R41, R45, R48, R49, R50, R52, R56, R59, R60, R61, R63, R67, R70, R71, R72, R74, R78, R81, R82, R83, R85, R89, R92, R93, R94, R96, R100, R103, R104, R105, R107, R111, R114, R115, R116, R118, R122, R125, R126, R127, R129: 10k; 0402-TIGHT
R3, R4, R5, R15, R21, R23, R28, R32, R34, R35, R40, R44, R46, R51, R55, R57, R62, R66, R68, R73, R77, R79, R84, R88, R90, R95, R99, R101, R106, R110, R112, R117, R121, R123, R128, R132: 1k; 0402-TIGHT
R6, R11, R24, R36, R47, R58, R69, R80, R91, R102, R113, R124: 2.0k; 0603
R9, R10, R19, R20, R30, R31, R42, R43, R53, R54, R64, R65, R75, R76, R86, R87, R97, R98, R108, R109, R119, R120, R130, R131: 5.1k; 0402-TIGHT
S1, S3, S5, S7, S9, S11, S13, S15, S17, S19, S21, S23: Boot; TACTILE_SWITCH_SMD_4.6X2.8MM
S2, S4, S6, S8, S10, S12, S14, S16, S18, S20, S22, S24: Reset; TACTILE_SWITCH_SMD_4.6X2.8MM
TP1, TP2, TP3, TP4, TP5, TP6, TP7, TP8, TP9, TP10, TP11, TP12, TP13, TP14, TP15, TP16, TP17, TP18, TP19, TP20, TP21, TP22, TP23, TP24, TP25, TP26, TP27, TP28, TP29, TP30, TP31, TP32, TP33, TP34, TP35, TP36, TP37, TP38, TP39, TP40, TP41, TP42, TP43, TP44, TP45, TP46, TP47, TP48: TEST-POINT3X5; PAD.03X.05
U1, U6, U13, U19, U25, U31, U37, U43, U49, U55, U61, U67: MCP73831; SOT23-5
U2, U12, U18, U24, U30, U36, U42, U48, U54, U60, U66, U72: ESP-WROOM-3232D-NARROW; ESP-WROOM-32D-NARROW
U3, U5, U10, U11, U16, U17, U22, U23, U28, U29, U34, U35, U40, U41, U46, U47, U52, U53, U58, U59, U64, U65, U70, U71: XC6222B331MR-G; SOT23-5
U4, U9, U15, U21, U27, U33, U39, U45, U51, U57, U63, U69: MAX17048; DFN-8
U7, U8, U14, U20, U26, U32, U38, U44, U50, U56, U62, U68: CH340C; SO016
U$1, U$57, U$145, U$197, U$249, U$301, U$353, U$405, U$457, U$509, U$561, U$613: SFE_LOGO_FLAME_STOP_.1
U$2, U$58, U$146, U$198, U$250, U$302, U$354, U$406, U$458, U$510, U$562, U$614: #23#PICO#0
U$3, U$59, U$147, U$199, U$251, U$303, U$355, U$407, U$459, U$511, U$563, U$615: #19#POCI#0
U$4, U$60, U$148, U$200, U$252, U$304, U$356, U$408, U$460, U$512, U$564, U$616: #4#FREE#0
U$5, U$61, U$149, U$201, U$253, U$305, U$357, U$409, U$461, U$513, U$565, U$617: #CHG_LED#0
U$6, U$62, U$150, U$202, U$254, U$306, U$358, U$410, U$462, U$514, U$566, U$618: ESP32#WROOM0
U$7, U$63, U$151, U$203, U$255, U$307, U$359, U$411, U$463, U$515, U$567, U$619: THING_PLUS_C0
U$8, U$82, U$156, U$208, U$260, U$312, U$364, U$416, U$468, U$520, U$572, U$624: #SHLD#0
U$9, U$64, U$152, U$204, U$256, U$308, U$360, U$412, U$464, U$516, U$568, U$620: #_GND#0
U$10, U$65, U$153, U$205, U$257, U$309, U$361, U$413, U$465, U$517, U$569, U$621: #_NC#0
U$11, U$66, U$154, U$206, U$258, U$310, U$362, U$414, U$466, U$518, U$570, U$622: #_3V3#0
U$12, U$67, U$155, U$207, U$259, U$311, U$363, U$415, U$467, U$519, U$571, U$623: SFE_LOGO_FLAME_.1
U$13, U$24, U$103, U$157, U$209, U$261, U$313, U$365, U$417, U$469, U$521, U$573: CHG1
U$14, U$25, U$104, U$158, U$210, U$262, U$314, U$366, U$418, U$470, U$522, U$574: PWR2
U$15, U$26, U$105, U$159, U$211, U$263, U$315, U$367, U$419, U$471, U$523, U$575: STAT0
U$16, U$68, U$106, U$160, U$212, U$264, U$316, U$368, U$420, U$472, U$524, U$576: A03
U$17, U$69, U$108, U$161, U$213, U$265, U$317, U$369, U$421, U$473, U$525, U$577: A12
U$18, U$70, U$110, U$162, U$214, U$266, U$318, U$370, U$422, U$474, U$526, U$578: A21
U$19, U$71, U$111, U$163, U$215, U$267, U$319, U$371, U$423, U$475, U$527, U$579: A30
U$20, U$74, U$112, U$164, U$216, U$268, U$320, U$372, U$424, U$476, U$528, U$580: EN3
U$21, U$77, U$113, U$165, U$217, U$269, U$321, U$373, U$425, U$477, U$529, U$581: 130
U$22, U$78, U$114, U$166, U$218, U$270, U$322, U$374, U$426, U$478, U$530, U$582: BOOT0
U$23, U$31, U$119, U$171, U$223, U$275, U$327, U$379, U$431, U$483, U$535, U$587: 3V30
U$27, U$54, U$79, U$109, U$115, U$142, U$167, U$194, U$219, U$246, U$271, U$298, U$323, U$350, U$375, U$402, U$427, U$454, U$479, U$506, U$531, U$558, U$583, U$610: #RST#0
U$28, U$80, U$116, U$168, U$220, U$272, U$324, U$376, U$428, U$480, U$532, U$584: RST0
U$29, U$73, U$117, U$169, U$221, U$273, U$325, U$377, U$429, U$481, U$533, U$585: VB1
U$30, U$76, U$118, U$170, U$222, U$274, U$326, U$378, U$430, U$482, U$534, U$586: VU0
U$32, U$72, U$120, U$172, U$224, U$276, U$328, U$380, U$432, U$484, U$536, U$588: #17#TX#0
U$33, U$81, U$121, U$173, U$225, U$277, U$329, U$381, U$433, U$485, U$537, U$589: #16#RX#0
U$34, U$83, U$122, U$174, U$226, U$278, U$330, U$382, U$434, U$486, U$538, U$590: #18#SCK#0
U$35, U$84, U$123, U$175, U$227, U$279, U$331, U$383, U$435, U$487, U$539, U$591: #35#A5#0
U$36, U$85, U$124, U$176, U$228, U$280, U$332, U$384, U$436, U$488, U$540, U$592: #36#A4#0
U$37, U$86, U$125, U$177, U$229, U$281, U$333, U$385, U$437, U$489, U$541, U$593: #25#A1#2
U$38, U$87, U$126, U$178, U$230, U$282, U$334, U$386, U$438, U$490, U$542, U$594: #26#A0#3
U$39, U$88, U$127, U$179, U$231, U$283, U$335, U$387, U$439, U$491, U$543, U$595: #34#A2#1
U$40, U$89, U$128, U$180, U$232, U$284, U$336, U$388, U$440, U$492, U$544, U$596: #39#A3#0
U$41, U$90, U$129, U$181, U$233, U$285, U$337, U$389, U$441, U$493, U$545, U$597: #12#4
U$42, U$91, U$130, U$182, U$234, U$286, U$338, U$390, U$442, U$494, U$546, U$598: #14#9
U$43, U$92, U$131, U$183, U$235, U$287, U$339, U$391, U$443, U$495, U$547, U$599: #15#7
U$44, U$93, U$132, U$184, U$236, U$288, U$340, U$392, U$444, U$496, U$548, U$600: #27#5
U$45, U$94, U$133, U$185, U$237, U$289, U$341, U$393, U$445, U$497, U$549, U$601: #32#8
U$46, U$95, U$134, U$186, U$238, U$290, U$342, U$394, U$446, U$498, U$550, U$602: #33#6
U$47, U$96, U$135, U$187, U$239, U$291, U$343, U$395, U$447, U$499, U$551, U$603: #EN#1
U$48, U$97, U$136, U$188, U$240, U$292, U$344, U$396, U$448, U$500, U$552, U$604: #VBAT#0
U$49, U$98, U$137, U$189, U$241, U$293, U$345, U$397, U$449, U$501, U$553, U$605: #VUSB#2
U$50, U$99, U$138, U$190, U$242, U$294, U$346, U$398, U$450, U$502, U$554, U$606: #13#LED#0
U$51, U$100, U$139, U$191, U$243, U$295, U$347, U$399, U$451, U$503, U$555, U$607: #21#SDA#1
U$52, U$101, U$140, U$192, U$244, U$296, U$348, U$400, U$452, U$504, U$556, U$608: #22#SCL#0
U$53, U$102, U$141, U$193, U$245, U$297, U$349, U$401, U$453, U$505, U$557, U$609: #PWR#0
U$55, U$75, U$143, U$195, U$247, U$299, U$351, U$403, U$455, U$507, U$559, U$611: GND1
U$56, U$107, U$144, U$196, U$248, U$300, U$352, U$404, U$456, U$508, U$560, U$612: NC0

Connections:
3.3V: C1.1, C2.1, C4.1, C5.1, C10.1, D5.VCC, J2.4, J5.27, JP1.2, R2.2, U2.2, U3.5, U7.4, U7.16
3.3V1: C9.1, C13.1, C14.1, C18.1, C20.1, D9.VCC, J9.4, J10.27, JP4.2, R14.2, U8.4, U8.16, U10.5, U12.2
3.3V2: C22.1, C25.1, C26.1, C29.1, C30.1, D15.VCC, J14.4, J15.27, JP7.2, R27.2, U14.4, U14.16, U16.5, U18.2
3.3V3: C32.1, C35.1, C36.1, C39.1, C40.1, D20.VCC, J19.4, J20.27, JP10.2, R39.2, U20.4, U20.16, U22.5, U24.2
3.3V4: C42.1, C45.1, C46.1, C49.1, C50.1, D25.VCC, J24.4, J25.27, JP13.2, R50.2, U26.4, U26.16, U28.5, U30.2
3.3V5: C52.1, C55.1, C56.1, C59.1, C60.1, D30.VCC, J29.4, J30.27, JP16.2, R61.2, U32.4, U32.16, U34.5, U36.2
3.3V6: C62.1, C65.1, C66.1, C69.1, C70.1, D35.VCC, J34.4, J35.27, JP19.2, R72.2, U38.4, U38.16, U40.5, U42.2
3.3V7: C72.1, C75.1, C76.1, C79.1, C80.1, D40.VCC, J39.4, J40.27, JP22.2, R83.2, U44.4, U44.16, U46.5, U48.2
3.3V8: C82.1, C85.1, C86.1, C89.1, C90.1, D45.VCC, J44.4, J45.27, JP25.2, R94.2, U50.4, U50.16, U52.5, U54.2
3.3V9: C92.1, C95.1, C96.1, C99.1, C100.1, D50.VCC, J49.4, J50.27, JP28.2, R105.2, U56.4, U56.16, U58.5, U60.2
3.3V10: C102.1, C105.1, C106.1, C109.1, C110.1, D55.VCC, J54.4, J55.27, JP31.2, R116.2, U62.4, U62.16, U64.5, U66.2
3.3V11: C112.1, C115.1, C116.1, C119.1, C120.1, D60.VCC, J59.4, J60.27, JP34.2, R127.2, U68.4, U68.16, U70.5, U72.2
!RESET!: J5.28, Q2.3, R2.1, S4.3, S4.4, U2.3
!RESET!1: J10.28, Q1.3, R14.1, S2.3, S2.4, U12.3
!RESET!2: J15.28, Q5.3, R27.1, S6.3, S6.4, U18.3
!RESET!3: J20.28, Q7.3, R39.1, S8.3, S8.4, U24.3
!RESET!4: J25.28, Q9.3, R50.1, S10.3, S10.4, U30.3
!RESET!5: J30.28, Q11.3, R61.1, S12.3, S12.4, U36.3
!RESET!6: J35.28, Q13.3, R72.1, S14.3, S14.4, U42.3
!RESET!7: J40.28, Q15.3, R83.1, S16.3, S16.4, U48.3
!RESET!8: J45.28, Q17.3, R94.1, S18.3, S18.4, U54.3
!RESET!9: J50.28, Q19.3, R105.1, S20.3, S20.4, U60.3
!RESET!10: J55.28, Q21.3, R116.1, S22.3, S22.4, U66.3
!RESET!11: J60.28, Q23.3, R127.1, S24.3, S24.4, U72.3
CH340-DTR: Q2.1, R17.1, U7.13
CH340-DTR1: Q1.1, R12.1, U8.13
CH340-DTR2: Q5.1, R25.1, U14.13
CH340-DTR3: Q7.1, R37.1, U20.13
CH340-DTR4: Q9.1, R48.1, U26.13
CH340-DTR5: Q11.1, R59.1, U32.13
CH340-DTR6: Q13.1, R70.1, U38.13
CH340-DTR7: Q15.1, R81.1, U44.13
CH340-DTR8: Q17.1, R92.1, U50.13
CH340-DTR9: Q19.1, R103.1, U56.13
CH340-DTR10: Q21.1, R114.1, U62.13
CH340-DTR11: Q23.1, R125.1, U68.13
CH340-RTS: Q2.4, R18.1, U7.14
CH340-RTS1: Q1.4, R13.1, U8.14
CH340-RTS2: Q5.4, R26.1, U14.14
CH340-RTS3: Q7.4, R38.1, U20.14
CH340-RTS4: Q9.4, R49.1, U26.14
CH340-RTS5: Q11.4, R60.1, U32.14
CH340-RTS6: Q13.4, R71.1, U38.14
CH340-RTS7: Q15.4, R82.1, U44.14
CH340-RTS8: Q17.4, R93.1, U50.14
CH340-RTS9: Q19.4, R104.1, U56.14
CH340-RTS10: Q21.4, R115.1, U62.14
CH340-RTS11: Q23.4, R126.1, U68.14
CH340-RX: U2.35, U7.3
CH340-RX1: U8.3, U12.35
CH340-RX2: U14.3, U18.35
CH340-RX3: U20.3, U24.35
CH340-RX4: U26.3, U30.35
CH340-RX5: U32.3, U36.35
CH340-RX6: U38.3, U42.35
CH340-RX7: U44.3, U48.35
CH340-RX8: U50.3, U54.35
CH340-RX9: U56.3, U60.35
CH340-RX10: U62.3, U66.35
CH340-RX11: U68.3, U72.35
CH340-TX: U2.34, U7.2
CH340-TX1: U8.2, U12.34
CH340-TX2: U14.2, U18.34
CH340-TX3: U20.2, U24.34
CH340-TX4: U26.2, U30.34
CH340-TX5: U32.2, U36.34
CH340-TX6: U38.2, U42.34
CH340-TX7: U44.2, U48.34
CH340-TX8: U50.2, U54.34
CH340-TX9: U56.2, U60.34
CH340-TX10: U62.2, U66.34
CH340-TX11: U68.2, U72.34
CHG_LED: D1.A, R3.2
CHG_LED1: D2.A, R5.2
CHG_LED2: D10.A, R23.2
CHG_LED3: D16.A, R35.2
CHG_LED4: D21.A, R46.2
CHG_LED5: D26.A, R57.2
CHG_LED6: D31.A, R68.2
CHG_LED7: D36.A, R79.2
CHG_LED8: D41.A, R90.2
CHG_LED9: D46.A, R101.2
CHG_LED10: D51.A, R112.2
CHG_LED11: D56.A, R123.2
D+: J1.A6, J1.B6, U7.5
D+1: J7.A6, J7.B6, U8.5
D+2: J12.A6, J12.B6, U14.5
D+3: J17.A6, J17.B6, U20.5
D+4: J22.A6, J22.B6, U26.5
D+5: J27.A6, J27.B6, U32.5
D+6: J32.A6, J32.B6, U38.5
D+7: J37.A6, J37.B6, U44.5
D+8: J42.A6, J42.B6, U50.5
D+9: J47.A6, J47.B6, U56.5
D+10: J52.A6, J52.B6, U62.5
D+11: J57.A6, J57.B6, U68.5
D-: J1.A7, J1.B7, U7.6
D-1: J7.A7, J7.B7, U8.6
D-2: J12.A7, J12.B7, U14.6
D-3: J17.A7, J17.B7, U20.6
D-4: J22.A7, J22.B7, U26.6
D-5: J27.A7, J27.B7, U32.6
D-6: J32.A7, J32.B7, U38.6
D-7: J37.A7, J37.B7, U44.6
D-8: J42.A7, J42.B7, U50.6
D-9: J47.A7, J47.B7, U56.6
D-10: J52.A7, J52.B7, U62.6
D-11: J57.A7, J57.B7, U68.6
DTR-10K: Q2.5, R17.2
DTR-10K1: Q1.5, R12.2
DTR-10K2: Q5.5, R25.2
DTR-10K3: Q7.5, R37.2
DTR-10K4: Q9.5, R48.2
DTR-10K5: Q11.5, R59.2
DTR-10K6: Q13.5, R70.2
DTR-10K7: Q15.5, R81.2
DTR-10K8: Q17.5, R92.2
DTR-10K9: Q19.5, R103.2
DTR-10K10: Q21.5, R114.2
DTR-10K11: Q23.5, R125.2
ESP_0/QPWR: Q2.6, S3.3, S3.4, TP1.1, U2.25, U5.3
ESP_0/QPWR1: Q1.6, S1.3, S1.4, TP5.1, U11.3, U12.25
ESP_0/QPWR2: Q5.6, S5.3, S5.4, TP9.1, U17.3, U18.25
ESP_0/QPWR3: Q7.6, S7.3, S7.4, TP13.1, U23.3, U24.25
ESP_0/QPWR4: Q9.6, S9.3, S9.4, TP17.1, U29.3, U30.25
ESP_0/QPWR5: Q11.6, S11.3, S11.4, TP21.1, U35.3, U36.25
ESP_0/QPWR6: Q13.6, S13.3, S13.4, TP25.1, U41.3, U42.25
ESP_0/QPWR7: Q15.6, S15.3, S15.4, TP29.1, U47.3, U48.25
ESP_0/QPWR8: Q17.6, S17.3, S17.4, TP33.1, U53.3, U54.25
ESP_0/QPWR9: Q19.6, S19.3, S19.4, TP37.1, U59.3, U60.25
ESP_0/QPWR10: Q21.6, S21.3, S21.4, TP41.1, U65.3, U66.25
ESP_0/QPWR11: Q23.6, S23.3, S23.4, TP45.1, U71.3, U72.25
ESP_2/RGB_DI: D5.DI, TP3.1, U2.24
ESP_2/RGB_DI1: D9.DI, TP7.1, U12.24
ESP_2/RGB_DI2: D15.DI, TP11.1, U18.24
ESP_2/RGB_DI3: D20.DI, TP15.1, U24.24
ESP_2/RGB_DI4: D25.DI, TP19.1, U30.24
ESP_2/RGB_DI5: D30.DI, TP23.1, U36.24
ESP_2/RGB_DI6: D35.DI, TP27.1, U42.24
ESP_2/RGB_DI7: D40.DI, TP31.1, U48.24
ESP_2/RGB_DI8: D45.DI, TP35.1, U54.24
ESP_2/RGB_DI9: D50.DI, TP39.1, U60.24
ESP_2/RGB_DI10: D55.DI, TP43.1, U66.24
ESP_2/RGB_DI11: D60.DI, TP47.1, U72.24
ESP_4/TP_FB: J5.13, U2.26
ESP_4/TP_FB1: J10.13, U12.26
ESP_4/TP_FB2: J15.13, U18.26
ESP_4/TP_FB3: J20.13, U24.26
ESP_4/TP_FB4: J25.13, U30.26
ESP_4/TP_FB5: J30.13, U36.26
ESP_4/TP_FB6: J35.13, U42.26
ESP_4/TP_FB7: J40.13, U48.26
ESP_4/TP_FB8: J45.13, U54.26
ESP_4/TP_FB9: J50.13, U60.26
ESP_4/TP_FB10: J55.13, U66.26
ESP_4/TP_FB11: J60.13, U72.26
ESP_5/SD_CS: J2.2, TP4.1, U2.29
ESP_5/SD_CS1: J9.2, TP8.1, U12.29
ESP_5/SD_CS2: J14.2, TP12.1, U18.29
ESP_5/SD_CS3: J19.2, TP16.1, U24.29
ESP_5/SD_CS4: J24.2, TP20.1, U30.29
ESP_5/SD_CS5: J29.2, TP24.1, U36.29
ESP_5/SD_CS6: J34.2, TP28.1, U42.29
ESP_5/SD_CS7: J39.2, TP32.1, U48.29
ESP_5/SD_CS8: J44.2, TP36.1, U54.29
ESP_5/SD_CS9: J49.2, TP40.1, U60.29
ESP_5/SD_CS10: J54.2, TP44.1, U66.29
ESP_5/SD_CS11: J59.2, TP48.1, U72.29
ESP_12/GPIO1: J5.8, U2.14
ESP_12/GPIO2: J10.8, U12.14
ESP_12/GPIO3: J15.8, U18.14
ESP_12/GPIO4: J20.8, U24.14
ESP_12/GPIO5: J25.8, U30.14
ESP_12/GPIO6: J30.8, U36.14
ESP_12/GPIO7: J35.8, U42.14
ESP_12/GPIO8: J40.8, U48.14
ESP_12/GPIO9: J45.8, U54.14
ESP_12/GPIO10: J50.8, U60.14
ESP_12/GPIO11: J55.8, U66.14
ESP_12/GPIO12: J60.8, U72.14
ESP_13/GPIO0/LED: J5.9, R4.1, U2.16
ESP_13/GPIO0/LED1: J10.9, R15.1, U12.16
ESP_13/GPIO0/LED2: J15.9, R28.1, U18.16
ESP_13/GPIO0/LED3: J20.9, R40.1, U24.16
ESP_13/GPIO0/LED4: J25.9, R51.1, U30.16
ESP_13/GPIO0/LED5: J30.9, R62.1, U36.16
ESP_13/GPIO0/LED6: J35.9, R73.1, U42.16
ESP_13/GPIO0/LED7: J40.9, R84.1, U48.16
ESP_13/GPIO0/LED8: J45.9, R95.1, U54.16
ESP_13/GPIO0/LED9: J50.9, R106.1, U60.16
ESP_13/GPIO0/LED10: J55.9, R117.1, U66.16
ESP_13/GPIO0/LED11: J60.9, R128.1, U72.16
ESP_14/GPIO1: J10.3, U12.13
ESP_14/GPIO2: J15.3, U18.13
ESP_14/GPIO3: J20.3, U24.13
ESP_14/GPIO4: J25.3, U30.13
ESP_14/GPIO5: J30.3, U36.13
ESP_14/GPIO6: J5.3, U2.13
ESP_14/GPIO7: J35.3, U42.13
ESP_14/GPIO8: J40.3, U48.13
ESP_14/GPIO9: J45.3, U54.13
ESP_14/GPIO10: J50.3, U60.13
ESP_14/GPIO11: J55.3, U66.13
ESP_14/GPIO12: J60.3, U72.13
ESP_15/GPIO1: J10.5, U12.23
ESP_15/GPIO2: J15.5, U18.23
ESP_15/GPIO3: J20.5, U24.23
ESP_15/GPIO4: J5.5, U2.23
ESP_15/GPIO5: J25.5, U30.23
ESP_15/GPIO6: J30.5, U36.23
ESP_15/GPIO7: J35.5, U42.23
ESP_15/GPIO8: J40.5, U48.23
ESP_15/GPIO9: J45.5, U54.23
ESP_15/GPIO10: J50.5, U60.23
ESP_15/GPIO11: J55.5, U66.23
ESP_15/GPIO12: J60.5, U72.23
ESP_16/TP_RX: J5.15, U2.27
ESP_16/TP_RX1: J10.15, U12.27
ESP_16/TP_RX2: J15.15, U18.27
ESP_16/TP_RX3: J20.15, U24.27
ESP_16/TP_RX4: J25.15, U30.27
ESP_16/TP_RX5: J30.15, U36.27
ESP_16/TP_RX6: J35.15, U42.27
ESP_16/TP_RX7: J40.15, U48.27
ESP_16/TP_RX8: J45.15, U54.27
ESP_16/TP_RX9: J50.15, U60.27
ESP_16/TP_RX10: J55.15, U66.27
ESP_16/TP_RX11: J60.15, U72.27
ESP_17/TP_TX: J5.14, U2.28
ESP_17/TP_TX1: J10.14, U12.28
ESP_17/TP_TX2: J15.14, U18.28
ESP_17/TP_TX3: J20.14, U24.28
ESP_17/TP_TX4: J25.14, U30.28
ESP_17/TP_TX5: J30.14, U36.28
ESP_17/TP_TX6: J35.14, U42.28
ESP_17/TP_TX7: J40.14, U48.28
ESP_17/TP_TX8: J45.14, U54.28
ESP_17/TP_TX9: J50.14, U60.28
ESP_17/TP_TX10: J55.14, U66.28
ESP_17/TP_TX11: J60.14, U72.28
ESP_18/TP_SCK: J2.5, J5.18, U2.30
ESP_18/TP_SCK1: J9.5, J10.18, U12.30
ESP_18/TP_SCK2: J14.5, J15.18, U18.30
ESP_18/TP_SCK3: J19.5, J20.18, U24.30
ESP_18/TP_SCK4: J24.5, J25.18, U30.30
ESP_18/TP_SCK5: J29.5, J30.18, U36.30
ESP_18/TP_SCK6: J34.5, J35.18, U42.30
ESP_18/TP_SCK7: J39.5, J40.18, U48.30
ESP_18/TP_SCK8: J44.5, J45.18, U54.30
ESP_18/TP_SCK9: J49.5, J50.18, U60.30
ESP_18/TP_SCK10: J54.5, J55.18, U66.30
ESP_18/TP_SCK11: J59.5, J60.18, U72.30
ESP_19/TP_POCI: J2.7, J5.16, U2.31
ESP_19/TP_POCI1: J9.7, J10.16, U12.31
ESP_19/TP_POCI2: J14.7, J15.16, U18.31
ESP_19/TP_POCI3: J19.7, J20.16, U24.31
ESP_19/TP_POCI4: J24.7, J25.16, U30.31
ESP_19/TP_POCI5: J29.7, J30.16, U36.31
ESP_19/TP_POCI6: J34.7, J35.16, U42.31
ESP_19/TP_POCI7: J39.7, J40.16, U48.31
ESP_19/TP_POCI8: J44.7, J45.16, U54.31
ESP_19/TP_POCI9: J49.7, J50.16, U60.31
ESP_19/TP_POCI10: J54.7, J55.16, U66.31
ESP_19/TP_POCI11: J59.7, J60.16, U72.31
ESP_21/TP_SDA: J3.3, J5.1, U2.33, U4.8
ESP_21/TP_SDA1: J6.3, J10.1, U9.8, U12.33
ESP_21/TP_SDA2: J11.3, J15.1, U15.8, U18.33
ESP_21/TP_SDA3: J16.3, J20.1, U21.8, U24.33
ESP_21/TP_SDA4: J21.3, J25.1, U27.8, U30.33
ESP_21/TP_SDA5: J26.3, J30.1, U33.8, U36.33
ESP_21/TP_SDA6: J31.3, J35.1, U39.8, U42.33
ESP_21/TP_SDA7: J36.3, J40.1, U45.8, U48.33
ESP_21/TP_SDA8: J41.3, J45.1, U51.8, U54.33
ESP_21/TP_SDA9: J46.3, J50.1, U57.8, U60.33
ESP_21/TP_SDA10: J51.3, J55.1, U63.8, U66.33
ESP_21/TP_SDA11: J56.3, J60.1, U69.8, U72.33
ESP_22/TP_SCL: J3.4, J5.2, U2.36, U4.7
ESP_22/TP_SCL1: J6.4, J10.2, U9.7, U12.36
ESP_22/TP_SCL2: J11.4, J15.2, U15.7, U18.36
ESP_22/TP_SCL3: J16.4, J20.2, U21.7, U24.36
ESP_22/TP_SCL4: J21.4, J25.2, U27.7, U30.36
ESP_22/TP_SCL5: J26.4, J30.2, U33.7, U36.36
ESP_22/TP_SCL6: J31.4, J35.2, U39.7, U42.36
ESP_22/TP_SCL7: J36.4, J40.2, U45.7, U48.36
ESP_22/TP_SCL8: J41.4, J45.2, U51.7, U54.36
ESP_22/TP_SCL9: J46.4, J50.2, U57.7, U60.36
ESP_22/TP_SCL10: J51.4, J55.2, U63.7, U66.36
ESP_22/TP_SCL11: J56.4, J60.2, U69.7, U72.36
ESP_23/TP_PICO: J2.3, J5.17, U2.37
ESP_23/TP_PICO1: J9.3, J10.17, U12.37
ESP_23/TP_PICO2: J14.3, J15.17, U18.37
ESP_23/TP_PICO3: J19.3, J20.17, U24.37
ESP_23/TP_PICO4: J24.3, J25.17, U30.37
ESP_23/TP_PICO5: J29.3, J30.17, U36.37
ESP_23/TP_PICO6: J34.3, J35.17, U42.37
ESP_23/TP_PICO7: J39.3, J40.17, U48.37
ESP_23/TP_PICO8: J44.3, J45.17, U54.37
ESP_23/TP_PICO9: J49.3, J50.17, U60.37
ESP_23/TP_PICO10: J54.3, J55.17, U66.37
ESP_23/TP_PICO11: J59.3, J60.17, U72.37
ESP_25/TP_A1: J5.23, U2.10
ESP_25/TP_A2: J10.23, U12.10
ESP_25/TP_A3: J15.23, U18.10
ESP_25/TP_A4: J20.23, U24.10
ESP_25/TP_A5: J25.23, U30.10
ESP_25/TP_A6: J30.23, U36.10
ESP_25/TP_A7: J35.23, U42.10
ESP_25/TP_A8: J40.23, U48.10
ESP_25/TP_A9: J45.23, U54.10
ESP_25/TP_A10: J50.23, U60.10
ESP_25/TP_A11: J55.23, U66.10
ESP_25/TP_A12: J60.23, U72.10
ESP_26/TP_A0: J5.24, U2.11
ESP_26/TP_A1: J10.24, U12.11
ESP_26/TP_A2: J15.24, U18.11
ESP_26/TP_A3: J20.24, U24.11
ESP_26/TP_A4: J25.24, U30.11
ESP_26/TP_A5: J30.24, U36.11
ESP_26/TP_A6: J35.24, U42.11
ESP_26/TP_A7: J40.24, U48.11
ESP_26/TP_A8: J45.24, U54.11
ESP_26/TP_A9: J50.24, U60.11
ESP_26/TP_A10: J55.24, U66.11
ESP_26/TP_A11: J60.24, U72.11
ESP_27/GPIO1: J10.7, U12.12
ESP_27/GPIO2: J5.7, U2.12
ESP_27/GPIO3: J15.7, U18.12
ESP_27/GPIO4: J20.7, U24.12
ESP_27/GPIO5: J25.7, U30.12
ESP_27/GPIO6: J30.7, U36.12
ESP_27/GPIO7: J35.7, U42.12
ESP_27/GPIO8: J40.7, U48.12
ESP_27/GPIO9: J45.7, U54.12
ESP_27/GPIO10: J50.7, U60.12
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

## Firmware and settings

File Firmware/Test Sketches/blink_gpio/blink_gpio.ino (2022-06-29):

void setup() {
  // put your setup code here, to run once:
  pinMode(21, OUTPUT);
  pinMode(22, OUTPUT);
  pinMode(14, OUTPUT);
  pinMode(32, OUTPUT);
  pinMode(15, OUTPUT);
  pinMode(33, OUTPUT);
  pinMode(27, OUTPUT);
  pinMode(12, OUTPUT);
  pinMode(13, OUTPUT);
  pinMode(26, OUTPUT);
  pinMode(25, OUTPUT);
  pinMode(34, OUTPUT);
  pinMode(39, OUTPUT);
  pinMode(36, OUTPUT);
  pinMode(35, OUTPUT);
  pinMode(18, OUTPUT);
  pinMode(23, OUTPUT);
  pinMode(19, OUTPUT);
  pinMode(16, OUTPUT);
  pinMode(17, OUTPUT);
}

void loop() {
  // put your main code here, to run repeatedly:
  digitalWrite(21, HIGH);
  delay(2000);
  digitalWrite(21, LOW);
  delay(2000);
  digitalWrite(22, HIGH);
  delay(2000);
  digitalWrite(22, LOW);
  delay(2000);
  digitalWrite(14, HIGH);
  delay(2000);
  digitalWrite(14, LOW);
  delay(2000);
  digitalWrite(32, HIGH);
  delay(2000);
  digitalWrite(32, LOW);
  delay(2000);
  digitalWrite(15, HIGH);
  delay(2000);
  digitalWrite(15, LOW);
  delay(2000);
  digitalWrite(33, HIGH);
  delay(2000);
  digitalWrite(33, LOW);
  delay(2000);
  digitalWrite(27, HIGH);
  delay(2000);
  digitalWrite(27, LOW);
  delay(2000);
  digitalWrite(12, HIGH);
  delay(2000);
  digitalWrite(12, LOW);
  delay(2000);
  digitalWrite(13, HIGH);
  delay(2000);
  digitalWrite(13, LOW);
  delay(2000);
  digitalWrite(26, HIGH);
  delay(2000);
  digitalWrite(26, LOW);
  delay(2000);
  digitalWrite(25, HIGH);
  delay(2000);
  digitalWrite(25, LOW);
  delay(2000);
  digitalWrite(18, HIGH);
  delay(2000);
  digitalWrite(18, LOW);
  delay(2000);
  digitalWrite(23, HIGH);
  delay(2000);
  digitalWrite(23, LOW);
  delay(2000);
  digitalWrite(19, HIGH);
  delay(2000);
  digitalWrite(19, LOW);
  delay(2000);
  digitalWrite(16, HIGH);
  delay(2000);
  digitalWrite(16, LOW);
  delay(2000);
  digitalWrite(17, HIGH);
  delay(2000);
  digitalWrite(17, LOW);
  delay(2000);
}

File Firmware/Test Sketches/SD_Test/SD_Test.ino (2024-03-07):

/*
  Written for ESP32
  Just test to see if we can read/write to an SD card over SPI

  Be sure to set the CS pin correctly at top of code below

  Common:
  1048576 bytes read for 3268 ms
  1048576 bytes written for 6269 ms
*/
#include "FS.h"
#include "SD.h"
#include <SPI.h>

#define SD_SCK 18
#define SD_MISO 19
#define SD_MOSI 23

const int sd_cs = 5; //Thing Plus C

void listDir(fs::FS &fs, const char * dirname, uint8_t levels) {
  Serial.printf("Listing directory: %s\n", dirname);

  File root = fs.open(dirname);
  if (!root) {
    Serial.println("Failed to open directory");
    return;
  }
  if (!root.isDirectory()) {
    Serial.println("Not a directory");
    return;
  }

  File file = root.openNextFile();
  while (file) {
    if (file.isDirectory()) {
      Serial.print("  DIR : ");
      Serial.println(file.name());
      if (levels) {
        listDir(fs, file.name(), levels - 1);
      }
    } else {
      Serial.print("  FILE: ");
      Serial.print(file.name());
      Serial.print("  SIZE: ");
      Serial.println(file.size());
    }
    file = root.openNextFile();
  }
}

void createDir(fs::FS &fs, const char * path) {
  Serial.printf("Creating Dir: %s\n", path);
  if (fs.mkdir(path)) {
    Serial.println("Dir created");
  } else {
    Serial.println("mkdir failed");
  }
}

void removeDir(fs::FS &fs, const char * path) {
  Serial.printf("Removing Dir: %s\n", path);
  if (fs.rmdir(path)) {
    Serial.println("Dir removed");
  } else {
    Serial.println("rmdir failed");
  }
}

void readFile(fs::FS &fs, const char * path) {
  Serial.printf("Reading file: %s\n", path);

  File file = fs.open(path);
  if (!file) {
    Serial.println("Failed to open file for reading");
    return;
  }

  Serial.print("Read from file: ");
  while (file.available()) {
    Serial.write(file.read());
  }
  file.close();
}

void writeFile(fs::FS &fs, const char * path, const char * message) {
  Serial.printf("Writing file: %s\n", path);

  File file = fs.open(path, FILE_WRITE);
  if (!file) {
    Serial.println("Failed to open file for writing");
    return;
  }
  if (file.print(message)) {
    Serial.println("File written");
  } else {
    Serial.println("Write failed");
  }
  file.close();
}

void appendFile(fs::FS &fs, const char * path, const char * message) {
  Serial.printf("Appending to file: %s\n", path);

  File file = fs.open(path, FILE_APPEND);
  if (!file) {
    Serial.println("Failed to open file for appending");
    return;
  }
  if (file.print(message)) {
    Serial.println("Message appended");
  } else {
    Serial.println("Append failed");
  }
  file.close();
}

void renameFile(fs::FS &fs, const char * path1, const char * path2) {
  Serial.printf("Renaming file %s to %s\n", path1, path2);
  if (fs.rename(path1, path2)) {
    Serial.println("File renamed");
  } else {
    Serial.println("Rename failed");
  }
}

void deleteFile(fs::FS &fs, const char * path) {
  Serial.printf("Deleting file: %s\n", path);
  if (fs.remove(path)) {
    Serial.println("File deleted");
  } else {
    Serial.println("Delete failed");
  }
}

void testFileIO(fs::FS &fs, const char * path) {
  File file = fs.open(path);
  static uint8_t buf[512];
  size_t len = 0;
  uint32_t start = millis();
  uint32_t end = start;
  if (file) {
    len = file.size();
    size_t flen = len;
    start = millis();
    while (len) {
      size_t toRead = len;
      if (toRead > 512) {
        toRead = 512;
      }
      file.read(buf, toRead);
      len -= toRead;
    }
    end = millis() - start;
    Serial.printf("%u bytes read for %u ms\n", flen, end);
    file.close();
  } else {
    Serial.println("Failed to open file for reading");
  }


  file = fs.open(path, FILE_WRITE);
  if (!file) {
    Serial.println("Failed to open file for writing");
    return;
  }

  size_t i;
  start = millis();
  for (i = 0; i < 2048; i++) {
    file.write(buf, 512);
  }
  end = millis() - start;
  Serial.printf("%u bytes written for %u ms\n", 2048 * 512, end);
  file.close();
}


void setup() {
  Serial.begin(115200);
  delay(1000);
  Serial.println("SD test");

  SPI.begin(SD_SCK, SD_MISO, SD_MOSI, sd_cs);
  delay(100);

  if (!SD.begin(sd_cs)) {
    Serial.println("Card Mount Failed");
    return;
  }
  uint8_t cardType = SD.cardType();

  if (cardType == CARD_NONE) {
    Serial.println("No SD card attached");
    return;
  }

  Serial.print("SD Card Type: ");
  if (cardType == CARD_MMC) {
    Serial.println("MMC");
  } else if (cardType == CARD_SD) {
    Serial.println("SDSC");
  } else if (cardType == CARD_SDHC) {
    Serial.println("SDHC");
  } else {
    Serial.println("UNKNOWN");
  }

  uint64_t cardSize = SD.cardSize() / (1024 * 1024);
  Serial.printf("SD Card Size: %lluMB\n", cardSize);

  listDir(SD, "/", 0);
  createDir(SD, "/mydir");
  listDir(SD, "/", 0);
  removeDir(SD, "/mydir");
  listDir(SD, "/", 2);
  writeFile(SD, "/hello.txt", "Hello ");
  appendFile(SD, "/hello.txt", "World!\n");
  readFile(SD, "/hello.txt");
  deleteFile(SD, "/foo.txt");
  renameFile(SD, "/hello.txt", "/foo.txt");
  readFile(SD, "/foo.txt");
  testFileIO(SD, "/test.txt");
  Serial.printf("Total space: %lluMB\n", SD.totalBytes() / (1024 * 1024));
  Serial.printf("Used space: %lluMB\n", SD.usedBytes() / (1024 * 1024));
}

void loop() {

}

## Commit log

2022-05-18 Pulled in files from SpX repo.
    Pulled in all the files from the SpX repo except production files and the old PDF schematic.
    [SparkFun ESP32 Thing Plus C.brd, SparkFun ESP32 Thing Plus C.sch]
2022-05-19 Renamed schematics, replaced parts with sfe lib parts.
    [SparkFun_Thing_Plus_ESP32_WROOM_C.brd, SparkFun_Thing_Plus_ESP32_WROOM_C.sch]
2022-05-19 All parts are now from SFE libs.
    [SparkFun_Thing_Plus_ESP32_WROOM_C.brd, SparkFun_Thing_Plus_ESP32_WROOM_C.sch]
2022-05-19 Placed all new components, pinned out PTHs.
    [SparkFun_Thing_Plus_ESP32_WROOM_C.brd, SparkFun_Thing_Plus_ESP32_WROOM_C.sch]
2022-05-19 End of day commit, placed uSD conn and began routing.
    [SparkFun_Thing_Plus_ESP32_WROOM_C.brd]
2022-05-20 Initial reroute complete.
    [SparkFun_Thing_Plus_ESP32_WROOM_C.brd, SparkFun_Thing_Plus_ESP32_WROOM_C.sch]
2022-05-23 Completed Board update pre-DR.
    [SparkFun_Thing_Plus_ESP32_WROOM_C.brd, SparkFun_Thing_Plus_ESP32_WROOM_C.sch]
2022-05-25 Completed updates post DR.
    Schematic:
    Change all text to vector, 8%
    Add row lines to boot mode table
    Add NC jumper on USB-C shield.
    Change 0.1u cap to 10u next to uSD.
    Update uSD device to pull in newest changes to keepout.
    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
    [SparkFun_Thing_Plus_ESP32_WROOM_C.brd, SparkFun_Thing_Plus_ESP32_WROOM_C.sch]
2022-05-26 Update post DR changes.
    Minor movement edits.
    [SparkFun_Thing_Plus_ESP32_WROOM_C.brd, SparkFun_Thing_Plus_ESP32_WROOM_C.sch]
2022-05-26 Increase board length to sit on 0.05" grid.
    Originally had only increased by 0.01", however was told that customers prefer 0.05" increments for designing around.
    [SparkFun_Thing_Plus_ESP32_WROOM_C.brd]
2022-05-26 Added 7-bit I2C address text.
    [SparkFun_Thing_Plus_ESP32_WROOM_C.sch]
2022-05-26 Panelized for production review.
    [SparkFun_Thing_Plus_ESP32_WROOM_C-Panel.brd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]
2022-05-26 Upload temp panel for Kasey.
    [SparkFun_Thing_Plus_ESP32_WROOM_C-Panel.brd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]
2022-05-26 Updated panel
    [SparkFun_Thing_Plus_ESP32_WROOM_C-Panel.brd]
2022-05-26 Cammed for ordering reds.
    [SparkFun_Thing_Plus_ESP32_WROOM_C-Panel.GBL, SparkFun_Thing_Plus_ESP32_WROOM_C-Panel.GBO, SparkFun_Thing_Plus_ESP32_WROOM_C-Panel.GBP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]
2022-06-29 Update BOM for cap mismatch.
    Accidentally placed C4/C5 in the wrong spot. Made the change in schematic so no board reorder is necessary.
    [SparkFun_Thing_Plus_ESP32_WROOM_C.brd, SparkFun_Thing_Plus_ESP32_WROOM_C.sch]
2023-06-21 BUGFIX: SD Card Mount Error on Thing Plus C
    [SD_Test.ino]
2023-07-19 Swap VREG IC
    [SparkFun_Thing_Plus_ESP32_WROOM_C.brd, SparkFun_Thing_Plus_ESP32_WROOM_C.sch]

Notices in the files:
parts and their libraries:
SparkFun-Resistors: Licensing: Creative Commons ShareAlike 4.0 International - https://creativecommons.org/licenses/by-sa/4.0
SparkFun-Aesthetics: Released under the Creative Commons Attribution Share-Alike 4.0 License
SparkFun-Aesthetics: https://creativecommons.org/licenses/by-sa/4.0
